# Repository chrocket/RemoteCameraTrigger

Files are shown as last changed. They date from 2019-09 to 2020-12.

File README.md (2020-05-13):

# RemoteCameraTrigger

SF30ReadEchoLCD2wWire  - Program  for - SF30 Lidar, LCD screen and trigger out to separate board with transmitter

CameraTriggerR2PCB  - PCB and software - Main camera trigger board using Adafruit LoRo module
CameraTriggerSensorNodeOnly - PCB and software - Sensor node only

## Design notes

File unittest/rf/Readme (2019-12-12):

RadioHead69_RawDemo_RX and RadioHead69_RawDemo_Tx are raw (broadcast send and receive)

 	Camera_remote_rx and  	Camera_remote_rx  are addressed (reliable versions)
  
  Used 	Camera_remote_rx for benchmarking, but used RadioHead69_RawDemo_RX RadioHead69_RawDemo_TX in the field

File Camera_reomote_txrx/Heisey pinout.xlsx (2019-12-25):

// inputs
LOWHIGH_TRIGGER_IN_PIN = 5; // If armed, Low to high transition will trigger
PUSH_IN_PIN=14; // Push button trigger overrided ("arm" does not have to be set)
ARM_IN_PIN=15; // Push button to arm sensor
POLLREQUEST_IN_PIN=16; // Push button to make roll call poll request
HIGHLOW_TRIGGER_IN_PIN=17; // If armed, High to low transition will trigger
DELAYMS_PIN=18; // Pot on analog in to set delay 0-200 ms
SPARE_PIN=19; // Reserved for future use
// outputs
// LED_OUT 13
BUZZER_OUT_PIN= 10; // Pin to audible indicator
CAMERA_TRIGGER_OUT_PIN = 11; // Pin for camera opto-isolator
CAMERA_FOCUS_OUT_PIN = 12; // Pin for focus opto-isoloatr
AUX_OUT_PIN = 9; // Pin for 2nd trigger output
ARM_INDICATOR_OUT_PIN = 6; // Indicates sensor is armed, turns laser on
ON_TIME_MS = 1000 ; // Camera bulb on time when trigger fires (typical vals 1-3 seconds)
SHORT_TIME_MS = 200;
 | RFM69_CS | 8
 | RFM69_INT | 3
 | RFM69_RESET | 4

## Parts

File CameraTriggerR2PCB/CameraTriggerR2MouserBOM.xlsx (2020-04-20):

Reference | Value | Footprint | Manf part no | Manf | Mouser PN | Datasheet
BZ1 | Buzzer | Buzzer_Beeper:Buzzer_TDK_PS1240P02BT_D12.2mm_H6.5mm | PS1240P02BT | TDK | 810-PS1240P02BT | ~
C1 | 25uf | Capacitor_THT:CP_Radial_Tantal_D5.0mm_P5.00mm | ESL107M016AC3AA | kmet | 80-ESL107M016AC3AA | ~
C2 | 0.1uf | Capacitor_THT:CP_Radial_Tantal_D5.0mm_P5.00mm | ESL106M100AE3AA | kimet | 80-ESL106M100AE3AA | ~
C3 | 0.01 uf | Capacitor_THT:C_Disc_D7.5mm_W2.5mm_P5.00mm | S103M47Z5UN63J7R | Vishay | 594-S103M47Z5UN63J7R
C4 | 0.01 uf | Capacitor_THT:C_Disc_D7.5mm_W2.5mm_P5.00mm | S103M47Z5UN63J7R | Vishay | 594-S103M47Z5UN63J7R
C5 | 0.01 uf | Capacitor_THT:C_Disc_D7.5mm_W2.5mm_P5.00mm | S103M47Z5UN63J7R | Vishay | 594-S103M47Z5UN63J7R
C6 | 0.01 uf | Capacitor_THT:C_Disc_D7.5mm_W2.5mm_P5.00mm | S103M47Z5UN63J7R | Vishay | 594-S103M47Z5UN63J7R
D1 | LED Arm |  | HLMP-1790 | Avago | 630-HLMP-1790 | ~
D2 | LED Trig |  | HLMP-K150 | Avago | 630-HLMP-K150 | ~
D3 | D |  | SBR10U45SD1-T | Diodes Incorporated | 621-SBR10U45SD1-T | DO-201AD-2
D4 | PWR |  | TLHK46Q1R2 | Vishay | 78-TLHK46Q1R2
D5 | Focus |  |  |  | HLMP-LG71-XZ0DD
IC1 | Feather M0 |  | 3178 | Adafruit | 485-3178
J1 | Power |  | XT30U-M | amass |  | https://www.tme.eu/Document/3cbfa5cfa544d79584972dd5234a409e/XT30U%20SPEC.pdf
J12 | 2.5 mm Camera Jack |  | SJ1-2503A | CUI | 490-SJ1-2503A
J11 | Ada2633 | 1x9 Header |  | Adafruit | 2633
J13 | 5V on | TerminalBlock_TE-Connectivity:TerminalBlock_TE_282834-2_1x02_P2.54mm_Horizontal | 282834-2 | TE | 571-282834-2
J14 | Pwr sw | TerminalBlock_TE-Connectivity:TerminalBlock_TE_282834-2_1x02_P2.54mm_Horizontal | 282834-2 | TE | 571-282834-2
J2 | Camera | Connector_Audio:Jack_3.5mm_CUI_SJ1-3533NG_Horizontal_CircularHoles | SJ1-3533NG | CUI | 490-SJ1-3533NG | ~https://www.mouser.com/datasheet/2/670/sj1-353xng-1313133.pdf
J3 | Aux out | TerminalBlock_TE-Connectivity:TerminalBlock_TE_282834-2_1x02_P2.54mm_Horizontal | 282834-2 | TE | 571-282834-2 | ~https://www.te.com/commerce/DocumentDelivery/DDEController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
J4 | Aux in | TerminalBlock_TE-Connectivity:TerminalBlock_TE_282834-3_1x03_P2.54mm_Horizontal | 282834-3 | TE | 571-2828343 | ~https://www.te.com/commerce/DocumentDelivery/DDEController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
J5 | Laser | TerminalBlock_TE-Connectivity:TerminalBlock_TE_282834-2_1x02_P2.54mm_Horizontal | 282834-2 | TE | 571-282834-2 | ~https://www.te.com/commerce/DocumentDelivery/DDEController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
J6 | Sensor | TerminalBlock_TE-Connectivity:TerminalBlock_TE_282834-3_1x03_P2.54mm_Horizontal | 282834-3 | TE | 571-2828343 | ~https://www.te.com/commerce/DocumentDelivery/DDEController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
J7 | Trig | TerminalBlock_TE-Connectivity:TerminalBlock_TE_282834-2_1x02_P2.54mm_Horizontal | 282834-2 | TE | 571-282834-2 | ~
J8 | Arm | TerminalBlock_TE-Connectivity:TerminalBlock_TE_282834-2_1x02_P2.54mm_Horizontal | 282834-2 | TE | 571-282834-2 | ~
Q1 | PN2222A | Package_TO_SOT_THT:TO-92_Inline | PN2222A | Central Semiconductor | 610-PN2222A | http://www.fairchildsemi.com/ds/PN/PN2222A.pdf
Q2 | PN2222A | Package_TO_SOT_THT:TO-92_Inline | PN2222A | Central Semiconductor | 610-PN2222A | http://www.fairchildsemi.com/ds/PN/PN2222A.pdf
Q3 | PN2222A | Package_TO_SOT_THT:TO-92_Inline | PN2222A | Central Semiconductor | 610-PN2222A | http://www.fairchildsemi.com/ds/PN/PN2222A.pdf
R1 | 1K | Resistor_THT:R_Axial_DIN0207_L6.3mm_D2.5mm_P7.62mm_Horizontal | MF1/4DCT26A1001F | KOA | 660-MF1/4DCT26A1001F | ~
R2 | 1k | Resistor_THT:R_Axial_DIN0207_L6.3mm_D2.5mm_P7.62mm_Horizontal | MF1/4DCT26A1001F | KOA | 660-MF1/4DCT26A1001F | ~
R3 | 5K | Resistor_THT:R_Axial_DIN0207_L6.3mm_D2.5mm_P7.62mm_Horizontal | MF1/4LCT52R472G | KOA | 660-MF1/4LCT52R472G | ~
R4 | 220
R5 | 1K | Resistor_THT:R_Axial_DIN0207_L6.3mm_D2.5mm_P7.62mm_Horizontal | MF1/4DCT26A1001F | KOA | 660-MF1/4DCT26A1001F | ~
R6 | 51 | Resistor_THT:R_Axial_DIN0207_L6.3mm_D2.5mm_P7.62mm_Horizontal | MF1/4LCT52R510G | KOA | 660-MF1/4LCT52R510G
R7 | 51 | Resistor_THT:R_Axial_DIN0207_L6.3mm_D2.5mm_P7.62mm_Horizontal | MF1/4LCT52R510G | KOA | 660-MF1/4LCT52R510G
R8 | 15K | Resistor_THT:R_Axial_DIN0207_L6.3mm_D2.5mm_P7.62mm_Horizontal |  |  | 603-MF0207FTE52-14K7
SW1 | SW_Power | Button_Switch_THT:SW_DIP_SPSTx01_Slide_9.78x4.72mm_W7.62mm_P2.54mm | AS11CB | NKK | 633-AS11CB | ~
SW2 | SW_Trigger | Button_Switch_THT:KSA_Tactile_SPST | KSA0A311LFTR | C&J | 611-KSA0A311LFT | ~http://www.ckswitches.com/media/1457/ksa_ksl.pdf
SW3 | SW_Poll | Button_Switch_THT:KSA_Tactile_SPST | KSA0A311LFTR | C&J | 611-KSA0A311LFT | ~http://www.ckswitches.com/media/1457/ksa_ksl.pdf
SW4 | SW_Arm | Button_Switch_THT:KSA_Tactile_SPST | KSA0A311LFTR | C&J | 611-KSA0A311LFT | ~http://www.ckswitches.com/media/1457/ksa_ksl.pdf
U1 | LM7805_TO220 | Package_TO_SOT_THT:TO-220-3_Vertical | LM7805CT | TI | 926-LM7805CT | http://www.fairchildsemi.com/ds/LM/LM7805.pdf
U2 | ILD74 | Package_DIP:DIP-6_W7.62mm | ILD74 | Vishay | 782-ILD74 | https://www.vishay.com/docs/83725/4n25.pdf
U3 | ILD74 | Package_DIP:DIP-6_W7.62mm | ILD74 | Vishay | 782-ILD74 | https://www.vishay.com/docs/83725/4n25.pdf
J11 |  | Connector_PinHeader_2.54mm:PinHeader_1x09_P2.54mm_Vertical | 2633 | Adafruit | 485-2633 | Adafruit Bluefruit LE SPI Friend - Bluetooth Low Energy (BLE)
 |  | Toggle switch | M2011SS1W01-BA | NKK | 633-M201101-BA
 |  | Project Box | 1591XXUSBK | Hammond | 546-1591XXUSBK
H1 |  | Standoffs | FC4542-632-A | Fascomp | 728-FC4542-632-A
H2 |  | Standoffs | FC4542-632-A | Fascomp | 728-FC4542-632-A
H3 |  | Standoffs | FC4542-632-A | Fascomp | 728-FC4542-632-A
H4 |  | Standoffs | FC4542-632-A | Fascomp | 728-FC4542-632-A

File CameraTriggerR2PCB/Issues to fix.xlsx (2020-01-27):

Rev 2 issues to fix
J1 symbols backwards on PCB | Fixed
2.5 mm has wrong footprint | TODO next rev; Use 3.5 mm
Headers 2830 should be regular not stacking 2886
R8 is wrong size
D5 missing HLMP-LG71-XZ0DD
J9, J10 too closely spaced
Need ground plane
Need wider trace for pwr
Watch square turns and T intersections
SW1 still has wrong spacing
Short 1 1K resister
Need AC decoupling caps
Add stensiling
Wrong footprint for J12

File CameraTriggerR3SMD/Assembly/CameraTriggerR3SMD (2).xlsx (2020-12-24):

Designator | Comment | Footprint | LCSC
BZ1 | Buzzer | Buzzer_Beeper:Buzzer_TDK_PS1240P02BT_D12.2mm_H6.5mm
C1 | 10u | Capacitor_SMD:C_1206_3216Metric | C13585
C2 | 4.7u | Capacitor_SMD:C_0603_1608Metric | C19666
C3 | 1u | Capacitor_SMD:C_0402_1005Metric | C52923
C4 | 4.7u | Capacitor_SMD:C_0603_1608Metric | C19666
C5 | 1u | Capacitor_SMD:C_0402_1005Metric | C52923
C6 | 0.01 Î¼F | Capacitor_SMD:C_0402_1005Metric | C1525
C7 | 0.01 Î¼F | Capacitor_SMD:C_0402_1005Metric | C1525
C8 | 0.01 Î¼F | Capacitor_SMD:C_0402_1005Metric | C1525
C9 | 0.01 Î¼F | Capacitor_SMD:C_0402_1005Metric | C1525
C10 | 10nf | Capacitor_SMD:C_0402_1005Metric | C15195
C11 | 10nf | Capacitor_SMD:C_0402_1005Metric | C15195
C12 | 10nf | Capacitor_SMD:C_0402_1005Metric | C15195
C13 | 10nf | Capacitor_SMD:C_0402_1005Metric | C15195
C14 | 4u7 | Capacitor_SMD:C_0603_1608Metric | C19666
C15 | 2u2 | Capacitor_SMD:C_0603_1608Metric | C23630
C16 | 100n | Capacitor_SMD:C_0402_1005Metric | C1525
C17 | 2u2 | Capacitor_SMD:C_0603_1608Metric | C23630
C18 | 100n | Capacitor_SMD:C_0402_1005Metric | C1525
C19 | 100n | Capacitor_SMD:C_0402_1005Metric | C1525
C20 | 100n | Capacitor_SMD:C_0402_1005Metric | C1525
C21 | 100n | Capacitor_SMD:C_0402_1005Metric | C1525
C22 | 1u | Capacitor_SMD:C_0402_1005Metric | C52923
C23 | 12p | Capacitor_SMD:C_0402_1005Metric | C1547
C24 | 10n | Capacitor_SMD:C_0402_1005Metric | C15195
C25 | 12p | Capacitor_SMD:C_0402_1005Metric | C1547
C26 | 100n | Capacitor_SMD:C_0402_1005Metric | C1525
C27 | 100n | Capacitor_SMD:C_0402_1005Metric | C1525
C28 | 10nf | Capacitor_SMD:C_0402_1005Metric | C15195
C29 | 100n | Capacitor_SMD:C_0402_1005Metric | C1525
C30 | 100n | Capacitor_SMD:C_0402_1005Metric | C1525
D1 | LED Trig (Red) | LED_SMD:LED_0603_1608Metric | C2286
D2 | LED Focus (Yellow) | LED_SMD:LED_0603_1608Metric | C72038
D3 | GREEN | LED_SMD:LED_0603_1608Metric | C72043
D4 | Red | LED_SMD:LED_0603_1608Metric | C2286
D5 | 1N4148W | Diode_SMD:D_SOD-323F | C2128
D6 | BLUE | LED_SMD:LED_0603_1608Metric | C72041
D7 | 19-237_R6GHBHC-A01_2T | 19237R6GHBHCA012T | C60105
F1 | 250mA | Fuse:Fuse_1206_3216Metric | C70068
FB1 | 600 @ 600 MHz | Inductor_SMD:L_0805_2012Metric | C1017
H1 | MountingHole_Pad | MountingHole:MountingHole_3.2mm_M3_Pad_Via
H2 | MountingHole_Pad | MountingHole:MountingHole_3.2mm_M3_Pad_Via
H3 | MountingHole_Pad | MountingHole:MountingHole_3.2mm_M3_Pad_Via
H4 | MountingHole_Pad | MountingHole:MountingHole_3.2mm_M3_Pad_Via
J1 | Camera 3.5mm | Connector_Audio:Jack_3.5mm_CUI_SJ1-3533NG_Horizontal_CircularHoles
J2 | Camera 2.5mm | CameraTriggerPCB:CUI_SJ1-2503A
J3 | Camera 3.5mm | Connector_Audio:Jack_3.5mm_CUI_SJ1-3533NG_Horizontal_CircularHoles
J4 | Camera 2.5mm | CameraTriggerPCB:CUI_SJ1-2503A
J5 | Sensor | TerminalBlock_TE-Connectivity:TerminalBlock_TE_282834-3_1x03_P2.54mm_Horizontal
J6 | Laser | TerminalBlock_TE-Connectivity:TerminalBlock_TE_282834-2_1x02_P2.54mm_Horizontal
J7 | XLR5 | SamacSys_Parts:Jack_XLR_Neutrik_NC5MBH_Horizontal
J8 | HighLowIn | TerminalBlock_TE-Connectivity:TerminalBlock_TE_282834-3_1x03_P2.54mm_Horizontal
J9 | Aux out | TerminalBlock_TE-Connectivity:TerminalBlock_TE_282834-2_1x02_P2.54mm_Horizontal
J10 | Trig | TerminalBlock_TE-Connectivity:TerminalBlock_TE_282834-2_1x02_P2.54mm_Horizontal
J11 | Arm | TerminalBlock_TE-Connectivity:TerminalBlock_TE_282834-2_1x02_P2.54mm_Horizontal
J12 | Conn_01x02 | Connector_AMASS:AMASS_XT30U-F_1x02_P5.0mm_Vertical
J13 | USB_B_Micro | Connector_USB:USB_Micro-B_Wuerth_629105150521
J14 | Qwiic_Connector | Connectors:1X04_1MM_RA_STRESSRELIEF
J15 | SWD | Connector_PinHeader_1.27mm:PinHeader_2x05_P1.27mm_Vertical_SMD
J16 | Conn_Coaxial | Connector_Coaxial:SMA_Amphenol_132289_EdgeMount
L1 | 39n | Inductor_SMD:L_0402_1005Metric | C26443
Q1 | S9103 | Package_TO_SOT_SMD:SOT-23 | C6749
Q2 | S9103 | Package_TO_SOT_SMD:SOT-23 | C6749
Q3 | AO3401A | Package_TO_SOT_SMD:SOT-23 | C15127
Q4 | S9103 | Package_TO_SOT_SMD:SOT-23 | C6749
Q5 | S9103 | Package_TO_SOT_SMD:SOT-23 | C6749
R1 | 47 | Resistor_SMD:R_0402_1005Metric | C25118
R2 | 1.5K | Resistor_SMD:R_0603_1608Metric | C22843
R3 | 47 | Resistor_SMD:R_0402_1005Metric | C25118
R4 | 1.5K | Resistor_SMD:R_0603_1608Metric | C22843
R5 | 20K | Resistor_SMD:R_0603_1608Metric | C4184
R6 | 10K | Resistor_SMD:R_0402_1005Metric | C25744
R7 | 1k5 | Resistor_SMD:R_0603_1608Metric | C22843
R8 | 1K | Resistor_SMD:R_0603_1608Metric | C21190
R9 | 15K | Resistor_SMD:R_0603_1608Metric | C22809
R10 | 1k5 | Resistor_SMD:R_0603_1608Metric | C22843
R11 | 5K | Resistor_SMD:R_0402_1005Metric | C25744
R12 | 1.5K | Resistor_SMD:R_0603_1608Metric | C22843
R13 | 47 | Resistor_SMD:R_0402_1005Metric | C25118
R14 | 10k | Resistor_SMD:R_0402_1005Metric | C25744
R15 | 2k2 | Resistor_SMD:R_0402_1005Metric | C25879
R16 | 2k2 | Resistor_SMD:R_0402_1005Metric | C25879
R17 | 22 | Resistor_SMD:R_0402_1005Metric | C25092
R18 | 22 | Resistor_SMD:R_0402_1005Metric | C25092
R19 | 22 | Resistor_SMD:R_0402_1005Metric | C25092
R20 | 22 | Resistor_SMD:R_0402_1005Metric | C25092
R21 | 1k5 | Resistor_SMD:R_0603_1608Metric | C22843
R22 | 1K | Resistor_SMD:R_0402_1005Metric | C11702
R23 | 1K | Resistor_SMD:R_0402_1005Metric | C11702
R24 | 1K | Resistor_SMD:R_0402_1005Metric | C11702
R25 | 100 | Resistor_SMD:R_0603_1608Metric | C22775
SW1 | SW_SPST | Button_Switch_THT:SW_DIP_SPSTx01_Slide_9.78x4.72mm_W7.62mm_P2.54mm
SW2 | SW_SPDT | Button_Switch_THT:SW_Slide_1P2T_CK_OS102011MS2Q
SW3 | SW_Trigger | Button_Switch_THT:KSA_Tactile_SPST | C127509
SW4 | SW_Arm | Button_Switch_THT:KSA_Tactile_SPST | C127509
SW5 | SW_Poll | Button_Switch_THT:KSA_Tactile_SPST | C127509
SW6 | SW_SPDT | Button_Switch_SMD:SW_SPDT_PCM12
SW7 | SW_Push | Button_Switch_SMD:SW_SPST_CK_KXT3
U1 | TLP291-4 | Package_SO:SOIC-16_4.55x10.3mm_P1.27mm | C60900
U2 | L7805 | Package_TO_SOT_SMD:TO-252-2 | C310413
U3 | UZ1084 | Package_TO_SOT_SMD:TO-252-2 | C84897
U4 | STM32F405RGTx | Package_QFP:LQFP-64_10x10mm_P0.5mm | C15742
U5 | RN4871 | RF_Module:Microchip_RN4871
U6 | RFM95W-915S2 | RF_Module:HOPERF_RFM9XW_THT
Y1 | Crystal_GND24_Small | Crystal:Crystal_SMD_3225-4Pin_3.2x2.5mm | C13738

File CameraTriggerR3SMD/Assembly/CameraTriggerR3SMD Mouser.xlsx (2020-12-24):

Designator | Comment | Footprint | Mouser | Digikey
BZ1 | Buzzer | Buzzer_Beeper:Buzzer_TDK_PS1240P02BT_D12.2mm_H6.5mm | 810-PS1240P02BT
J1 | Camera 3.5mm | Connector_Audio:Jack_3.5mm_CUI_SJ1-3533NG_Horizontal_CircularHoles | 490-SJ1-3533NG
J2 | Camera 2.5mm | CameraTriggerPCB:CUI_SJ1-2503A | 490-SJ1-2503A
J3 | Camera 3.5mm | Connector_Audio:Jack_3.5mm_CUI_SJ1-3533NG_Horizontal_CircularHoles | 490-SJ1-3533NG
J4 | Camera 2.5mm | CameraTriggerPCB:CUI_SJ1-2503A | 490-SJ1-2503A
J5 | Sensor | TerminalBlock_TE-Connectivity:TerminalBlock_TE_282834-3_1x03_P2.54mm_Horizontal | 571-2828343
J6 | Laser | TerminalBlock_TE-Connectivity:TerminalBlock_TE_282834-2_1x02_P2.54mm_Horizontal | 571-282834-2
J7 | XLR5 | SamacSys_Parts:Jack_XLR_Neutrik_NC5MBH_Horizontal | 568-NC5MBH
J8 | HighLowIn | TerminalBlock_TE-Connectivity:TerminalBlock_TE_282834-3_1x03_P2.54mm_Horizontal | 571-2828343
J9 | Aux out | TerminalBlock_TE-Connectivity:TerminalBlock_TE_282834-2_1x02_P2.54mm_Horizontal | 571-282834-2
J10 | Trig | TerminalBlock_TE-Connectivity:TerminalBlock_TE_282834-2_1x02_P2.54mm_Horizontal | 571-282834-2
J11 | Arm | TerminalBlock_TE-Connectivity:TerminalBlock_TE_282834-2_1x02_P2.54mm_Horizontal | 571-282834-2
J13 | USB_B_Micro | Connector_USB:USB_Micro-B_Wuerth_629105150521 | 629105150521
J14 | Qwiic_Connector | Connectors:1X04_1MM_RA_STRESSRELIEF | 474-PRT-14417
J15 | SWD | Connector_PinHeader_1.27mm:PinHeader_2x05_P1.27mm_Vertical_SMD | FTR-105-01-L-D-A
J16 | Conn_Coaxial | Connector_Coaxial:SMA_Amphenol_132289_EdgeMount | 523-132289
SW1 | SW_SPST | Button_Switch_THT:SW_DIP_SPSTx01_Slide_9.78x4.72mm_W7.62mm_P2.54mm | 633-AS11CB
SW2 | SW_SPDT | Button_Switch_THT:SW_Slide_1P2T_CK_OS102011MS2Q | 611-OS102011MS2QN1
SW6 | SW_SPDT | Button_Switch_SMD:SW_SPDT_PCM12 | PCM12SMTR
SW7 | SW_Push | Button_Switch_SMD:SW_SPST_CK_KXT3 | 611-KXT321LHS
U5 | RN4871 | RF_Module:Microchip_RN4871 |  | RN4871-V/RM118-ND
U6 | RFM95W-915S2 | RF_Module:HOPERF_RFM9XW_THT | 223-RFM95W-915S2 | RFM95W-915S2-ND | 1597-1491-ND
 |  | Programmer ST-LINK/V2 | 511-ST-LINK/V2 | 497-10484-ND
 |  | Adapter ARM-JTAG-20-10 | 909-ARM-JTAG-20-10 | 1188-1016-ND

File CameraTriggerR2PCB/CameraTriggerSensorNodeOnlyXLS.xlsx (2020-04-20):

Item | Qty | Reference(s) | Value | Manf part no | Manf | Mouser PN
1 | 1 | BZ1 | Buzzer | PS1240P02BT | TDK | 810-PS1240P02BT
2 | 1 | C1 | 25uf | ESL107M016AC3AA | kmet | 80-ESL107M016AC3AA
3 | 1 | C2 | 0.1uf | ESL106M100AE3AA | kimet | 80-ESL106M100AE3AA
4 | 4 | C3, C4, C5, C6 | 0.01uF | S103M47Z5UN63J7R | Vishay | 594-S103M47Z5UN63J7R | 72-VY2103M63Y5US63V0
5 | 1 | D1 | LED Arm | HLMP-1790 | Avago | 630-HLMP-1790
6 | 1 | D2 | LED Trig | HLMP-K150 | Avago | 630-HLMP-K150
7 | 1 | D3 | D | SBR10U45SD1-T | Diodes Incorporated | 621-SBR10U45SD1-T
8 | 1 | D4 | PWR | TLHK46Q1R2 | Vishay | 78-TLHK46Q1R2
12 | 1 | IC1 | 3178 | 3178 | Adafruit | 485-3178
13 | 1 | J1 | Power | 282834-2 | TE | 571-282834-2
14 | 1 | J2 | Qwiic_Connector | PRT-14417 | Sparkfun | 474-PRT-14417
15 | 1 | J3 | Aux out | 282834-2 | TE | 571-282834-2
16 | 1 | J4 | HighLowIn | 282834-3 | TE | 571-2828343
17 | 1 | J5 | Laser | 282834-2 | TE | 571-282834-2
18 | 1 | J6 | Sensor | 282834-3 | TE | 571-2828343
19 | 1 | J13 | Serial | 282834-4 | TE | 571-282834-4
20 | 1 | J14 | Ext power switch | 282834-2 | TE | 571-282834-2
21 | 1 | Q1 | PN2222A | PN2222A | Central Semiconductor | 610-PN2222A
22 | 2 | R1, R5 | 1K | MF1/4DCT26A1001F | KOA | 660-MF1/4DCT26A1001F | 603-MF0204FTE52-1K | 660-MF1/4DCT26A1001F
23 | 1 | R3 | 5K | MF1/4LCT52R472G | KOA | 660-MF1/4LCT52R472G
24 | 1 | R4 | 220 |  |  | 603-MF0207FTE52-14K7
25 | 1 | R8 | 15K |  |  | 603-MF0207FTE52-14K7
26 | 1 | RV1 | 1K | RK09K1130AV7 | Alps | 688-RK09K1130AV7
27 | 1 | SW1 | AS11CB | AS11CB | NKK | 633-AS11CB
28 | 1 | SW3 | SW_Poll | KSA0A311LFTR | C&J | 611-KSA0A311LFT
29 | 1 | U1 | LM7805_TO220 | LM7805CT | TI | 926-LM7805CT
 | 1 |  | Connector_PinHeader_2.54mm:PinHeader_1x09_P2.54mm_Vertical | 2886 | Adafruit | 485-2886
 | 1 |  | Toggle switch | M2011SS1W01-BA | NKK | 633-M201101-BA
 | 1 |  | Project Box | 1591XXUSBK | Hammond | 546-1591XXUSBK
 | 4 |  | Standoffs | FC4542-632-A | Fascomp | 728-FC4542-632-A

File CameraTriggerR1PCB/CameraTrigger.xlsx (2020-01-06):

Reference | Value | Footprint |  |  | Mouser PN | Datasheet
BZ1 | Buzzer | Buzzer_Beeper:Buzzer_TDK_PS1240P02BT_D12.2mm_H6.5mm | PS1240P02BT | TDK | 810-PS1240P02BT | ~
C1 | 25uf | Capacitor_THT:CP_Radial_Tantal_D5.0mm_P5.00mm | ESL107M016AC3AA | kmet | 80-ESL107M016AC3AA | ~
C2 | 0.1uf | Capacitor_THT:CP_Radial_Tantal_D5.0mm_P5.00mm | ESL106M100AE3AA | kimet | 80-ESL106M100AE3AA | ~
D1 | LED Arm | LED_THT:LED_D2.0mm_W4.8mm_H2.5mm_FlatTop | HLMP-1790 | Avago | 630-HLMP-1790 | ~
D2 | LED Trig | LED_THT:LED_D2.0mm_W4.8mm_H2.5mm_FlatTop | HLMP-NG07 | Avago | 630-HLMP-NG07 | ~
D3 |  |  | SBR10U45SD1-T | Diodes Incorporated | 621-SBR10U45SD1-T | DO-201AD-2
J1 | Power | TerminalBlock_TE-Connectivity:TerminalBlock_TE_282834-2_1x02_P2.54mm_Horizontal | 282834-2 | TE | 571-282834-2 | ~https://www.te.com/commerce/DocumentDelivery/DDEController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
J10 | feather short | Connector_PinHeader_2.54mm:PinHeader_1x12_P2.54mm_Vertical | 2830 | Adafruit | 485-2830 | ~
J4 | Aux in | TerminalBlock_TE-Connectivity:TerminalBlock_TE_282834-3_1x03_P2.54mm_Horizontal | 282834-3 | TE | 571-2828343 | ~https://www.te.com/commerce/DocumentDelivery/DDEController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
J2 | Camera | Connector_Audio:Jack_3.5mm_CUI_SJ1-3533NG_Horizontal_CircularHoles | SJ1-3533NG | CUI | 490-SJ1-3533NG | ~https://www.mouser.com/datasheet/2/670/sj1-353xng-1313133.pdf
J3 | Aux out | TerminalBlock_TE-Connectivity:TerminalBlock_TE_282834-2_1x02_P2.54mm_Horizontal | 282834-2 | TE | 571-282834-2 | ~https://www.te.com/commerce/DocumentDelivery/DDEController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
J5 | Laser | TerminalBlock_TE-Connectivity:TerminalBlock_TE_282834-2_1x02_P2.54mm_Horizontal | 282834-2 | TE | 571-282834-2 | ~https://www.te.com/commerce/DocumentDelivery/DDEController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
J6 | Sensor | TerminalBlock_TE-Connectivity:TerminalBlock_TE_282834-3_1x03_P2.54mm_Horizontal | 282834-3 | TE | 571-2828343 | ~https://www.te.com/commerce/DocumentDelivery/DDEController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
J7 | Trig | TerminalBlock_TE-Connectivity:TerminalBlock_TE_282834-2_1x02_P2.54mm_Horizontal | 282834-2 | TE | 571-282834-2 | ~
J8 | Arm | TerminalBlock_TE-Connectivity:TerminalBlock_TE_282834-2_1x02_P2.54mm_Horizontal | 282834-2 | TE | 571-282834-2 | ~
Q1 | PN2222A | Package_TO_SOT_THT:TO-92_Inline | PN2222A | Central Semiconductor | 610-PN2222A | http://www.fairchildsemi.com/ds/PN/PN2222A.pdf
Q2 | PN2222A | Package_TO_SOT_THT:TO-92_Inline | PN2222A | Central Semiconductor | 610-PN2222A | http://www.fairchildsemi.com/ds/PN/PN2222A.pdf
Q3 | PN2222A | Package_TO_SOT_THT:TO-92_Inline | PN2222A | Central Semiconductor | 610-PN2222A | http://www.fairchildsemi.com/ds/PN/PN2222A.pdf
R1 | 1K | Resistor_THT:R_Axial_DIN0207_L6.3mm_D2.5mm_P7.62mm_Horizontal | MF1/4DCT26A1001F | KOA | 660-MF1/4DCT26A1001F | ~
R2 | 1k | Resistor_THT:R_Axial_DIN0207_L6.3mm_D2.5mm_P7.62mm_Horizontal | MF1/4DCT26A1001F | KOA | 660-MF1/4DCT26A1001F | ~
R3 | 5K | Resistor_THT:R_Axial_DIN0207_L6.3mm_D2.5mm_P7.62mm_Horizontal | MF1/4LCT52R472G | KOA | 660-MF1/4LCT52R472G | ~
R5 | 1K | Resistor_THT:R_Axial_DIN0207_L6.3mm_D2.5mm_P7.62mm_Horizontal | MF1/4DCT26A1001F | KOA | 660-MF1/4DCT26A1001F | ~
SW1 | SW_Power | Button_Switch_THT:SW_DIP_SPSTx01_Slide_9.78x4.72mm_W7.62mm_P2.54mm | AS11BH | NKK | 633-AS11BH | ~
SW2 | SW_Trigger | Button_Switch_THT:KSA_Tactile_SPST | KSA0A311LFTR | C&J | 611-KSA0A311LFT | ~http://www.ckswitches.com/media/1457/ksa_ksl.pdf
SW3 | SW_Poll | Button_Switch_THT:KSA_Tactile_SPST | KSA0A311LFTR | C&J | 611-KSA0A311LFT | ~http://www.ckswitches.com/media/1457/ksa_ksl.pdf
SW4 | SW_Arm | Button_Switch_THT:KSA_Tactile_SPST | KSA0A311LFTR | C&J | 611-KSA0A311LFT | ~http://www.ckswitches.com/media/1457/ksa_ksl.pdf
U1 | LM7805_TO220 | Package_TO_SOT_THT:TO-220-3_Vertical | LM7805CT | TI | 926-LM7805CT | http://www.fairchildsemi.com/ds/LM/LM7805.pdf
U2 | ILD74 | Package_DIP:DIP-6_W7.62mm | ILD74 | Vishay | 782-ILD74 | https://www.vishay.com/docs/83725/4n25.pdf
U3 | ILD74 | Package_DIP:DIP-6_W7.62mm | ILD74 | Vishay | 782-ILD74 | https://www.vishay.com/docs/83725/4n25.pdf
U6 | Feather M0 |  | 3176 | Adafruit | 485-3176
J12 | 2.5 mm Camera Jack |  | SJ1-2503A | CUI | 490-SJ1-2503A
U7 |  | Connector_PinHeader_2.54mm:PinHeader_1x09_P2.54mm_Vertical | 2633 | Adafruit |  | Adafruit Bluefruit LE SPI Friend - Bluetooth Low Energy (BLE)

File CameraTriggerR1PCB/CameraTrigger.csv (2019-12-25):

Reference | Value | Footprint | Datasheet
J3 | Aux out | TerminalBlock_TE-Connectivity:TerminalBlock_TE_282834-2_1x02_P2.54mm_Horizontal | ~https://www.te.com/commerce/DocumentDelivery/DDEController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
J4 | Aux in | TerminalBlock_TE-Connectivity:TerminalBlock_TE_282834-2_1x02_P2.54mm_Horizontal | ~https://www.te.com/commerce/DocumentDelivery/DDEController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
J5 | Laser | TerminalBlock_TE-Connectivity:TerminalBlock_TE_282834-2_1x02_P2.54mm_Horizontal | ~https://www.te.com/commerce/DocumentDelivery/DDEController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
J6 | Sensor | TerminalBlock_TE-Connectivity:TerminalBlock_TE_282834-3_1x03_P2.54mm_Horizontal | ~https://www.te.com/commerce/DocumentDelivery/DDEController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
SW2 | SW_Trigger | Button_Switch_THT:KSA_Tactile_SPST | ~http://www.ckswitches.com/media/1457/ksa_ksl.pdf
SW4 | SW_Arm | Button_Switch_THT:KSA_Tactile_SPST | ~http://www.ckswitches.com/media/1457/ksa_ksl.pdf
SW3 | SW_Poll | Button_Switch_THT:KSA_Tactile_SPST | ~http://www.ckswitches.com/media/1457/ksa_ksl.pdf
U2 | 4N25 | Package_DIP:DIP-6_W7.62mm | https://www.vishay.com/docs/83725/4n25.pdf
D1 | LED Arm | LED_THT:LED_D2.0mm_W4.8mm_H2.5mm_FlatTop | ~
R1 | 1K | Resistor_THT:R_Axial_DIN0207_L6.3mm_D2.5mm_P7.62mm_Horizontal | ~
J2 | Camera | Connector_Audio:Jack_3.5mm_CUI_SJ1-3533NG_Horizontal_CircularHoles | ~https://www.mouser.com/datasheet/2/670/sj1-353xng-1313133.pdf
R2 | 220 | Resistor_THT:R_Axial_DIN0207_L6.3mm_D2.5mm_P7.62mm_Horizontal | ~
BZ1 | Buzzer | Buzzer_Beeper:Buzzer_TDK_PS1240P02BT_D12.2mm_H6.5mm | ~
J7 | Trig | TerminalBlock_TE-Connectivity:TerminalBlock_TE_282834-2_1x02_P2.54mm_Horizontal | ~
J8 | Arm | TerminalBlock_TE-Connectivity:TerminalBlock_TE_282834-2_1x02_P2.54mm_Horizontal | ~
D2 | LED Trig | LED_THT:LED_D2.0mm_W4.8mm_H2.5mm_FlatTop | ~
R3 | 5K | Resistor_THT:R_Axial_DIN0207_L6.3mm_D2.5mm_P7.62mm_Horizontal | ~
Q1 | PN2222A | Package_TO_SOT_THT:TO-92_Inline | http://www.fairchildsemi.com/ds/PN/PN2222A.pdf
J9 | feather long | Connector_PinHeader_2.54mm:PinHeader_1x16_P2.54mm_Vertical | ~
J10 | feather short | Connector_PinHeader_2.54mm:PinHeader_1x12_P2.54mm_Vertical | ~
J11 | Spare | TerminalBlock_TE-Connectivity:TerminalBlock_TE_282834-2_1x02_P2.54mm_Horizontal | ~https://www.te.com/commerce/DocumentDelivery/DDEController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
R4 | 5K | Resistor_THT:R_Axial_DIN0207_L6.3mm_D2.5mm_P7.62mm_Horizontal | ~
U3 | 4N25 | Package_DIP:DIP-6_W7.62mm | https://www.vishay.com/docs/83725/4n25.pdf
R5 | 220 | Resistor_THT:R_Axial_DIN0207_L6.3mm_D2.5mm_P7.62mm_Horizontal | ~
RV1 | 10K | Potentiometer_THT:Potentiometer_Alps_RK09K_Single_Vertical | ~
C2 | 0.1uf | Capacitor_THT:CP_Radial_Tantal_D5.0mm_P5.00mm | ~
C1 | 25uf | Capacitor_THT:CP_Radial_Tantal_D5.0mm_P5.00mm | ~
J1 | Power | TerminalBlock_TE-Connectivity:TerminalBlock_TE_282834-2_1x02_P2.54mm_Horizontal | ~https://www.te.com/commerce/DocumentDelivery/DDEController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
SW1 | SW_Power | Button_Switch_THT:SW_DIP_SPSTx01_Slide_9.78x4.72mm_W7.62mm_P2.54mm | ~
U1 | LM7805_TO220 | Package_TO_SOT_THT:TO-220-3_Vertical | http://www.fairchildsemi.com/ds/LM/LM7805.pdf

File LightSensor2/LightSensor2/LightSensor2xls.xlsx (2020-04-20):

 | Designator | Package |  | Quantity | Mouser
1 | U1 | DIP-8_W7.62mm_LongPads | 1 | LTC1050CN8PBF | 584-LTC1050CN8#PBF
2 | J1 | TerminalBlock_TE_282834-3_1x03_P2.54mm_Horizontal | 1 | J1 | 571-2828343
3 | D1 | LED_D5.0mm_IRGrey | 1 | SFH229 | 720-SFH229FA
4 | 10K1 | R_Axial_DIN0207_L6.3mm_D2.5mm_P10.16mm_Horizontal | 1 | R | MF0207FTE52-10K
 |  |  |  |  | 720-SFH229

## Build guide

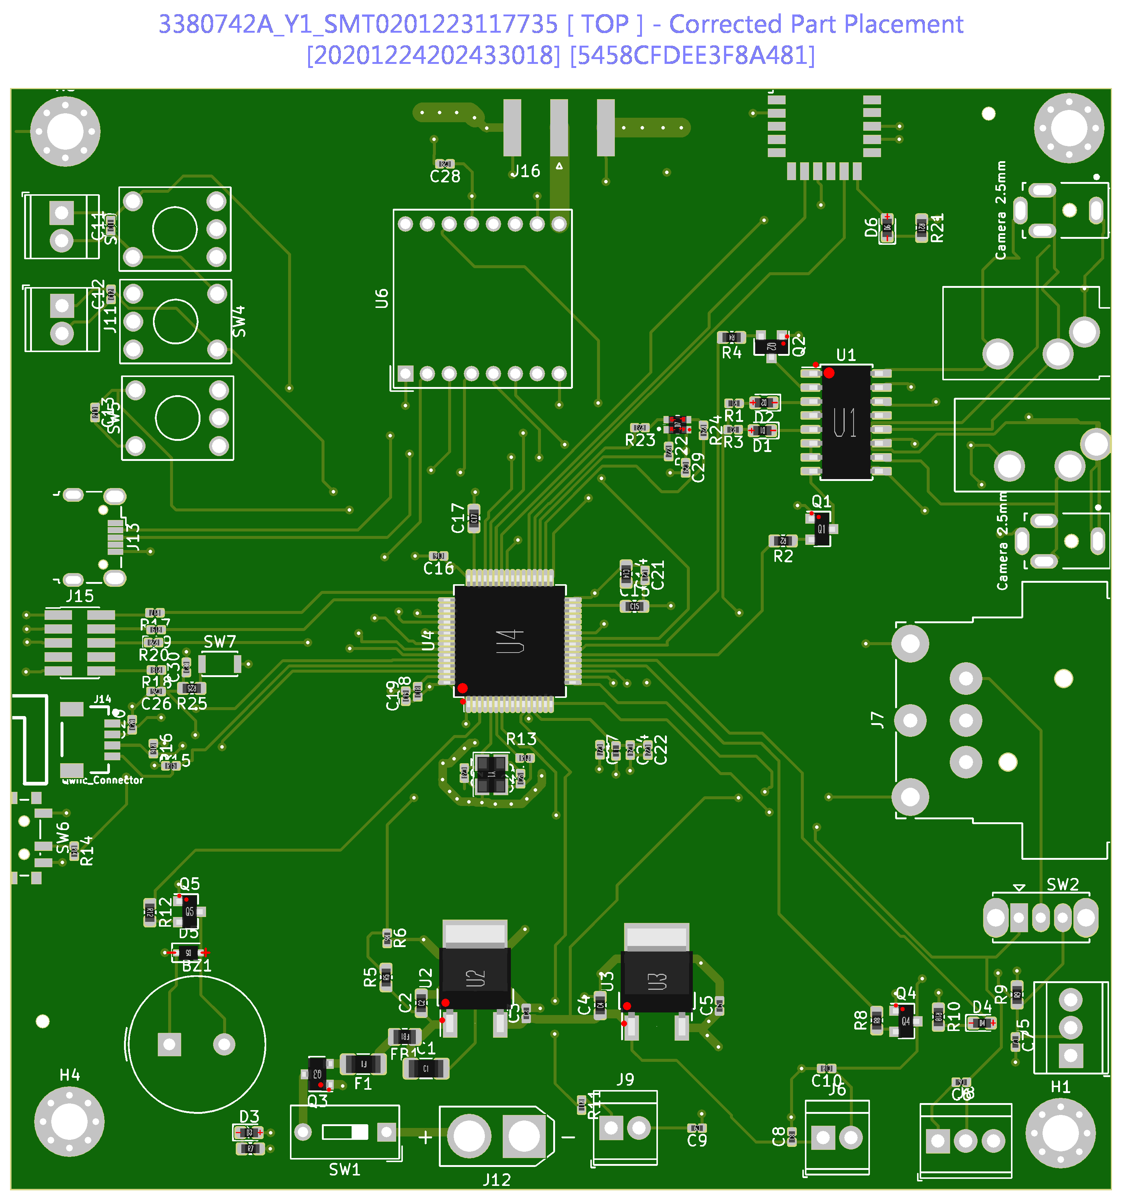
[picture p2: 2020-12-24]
CameraTriggerR3SMD/Assembly/Produce_DanZhi.SMT_Snapshot.Top.3380742A_Y1.SMT0201223117735(1).png

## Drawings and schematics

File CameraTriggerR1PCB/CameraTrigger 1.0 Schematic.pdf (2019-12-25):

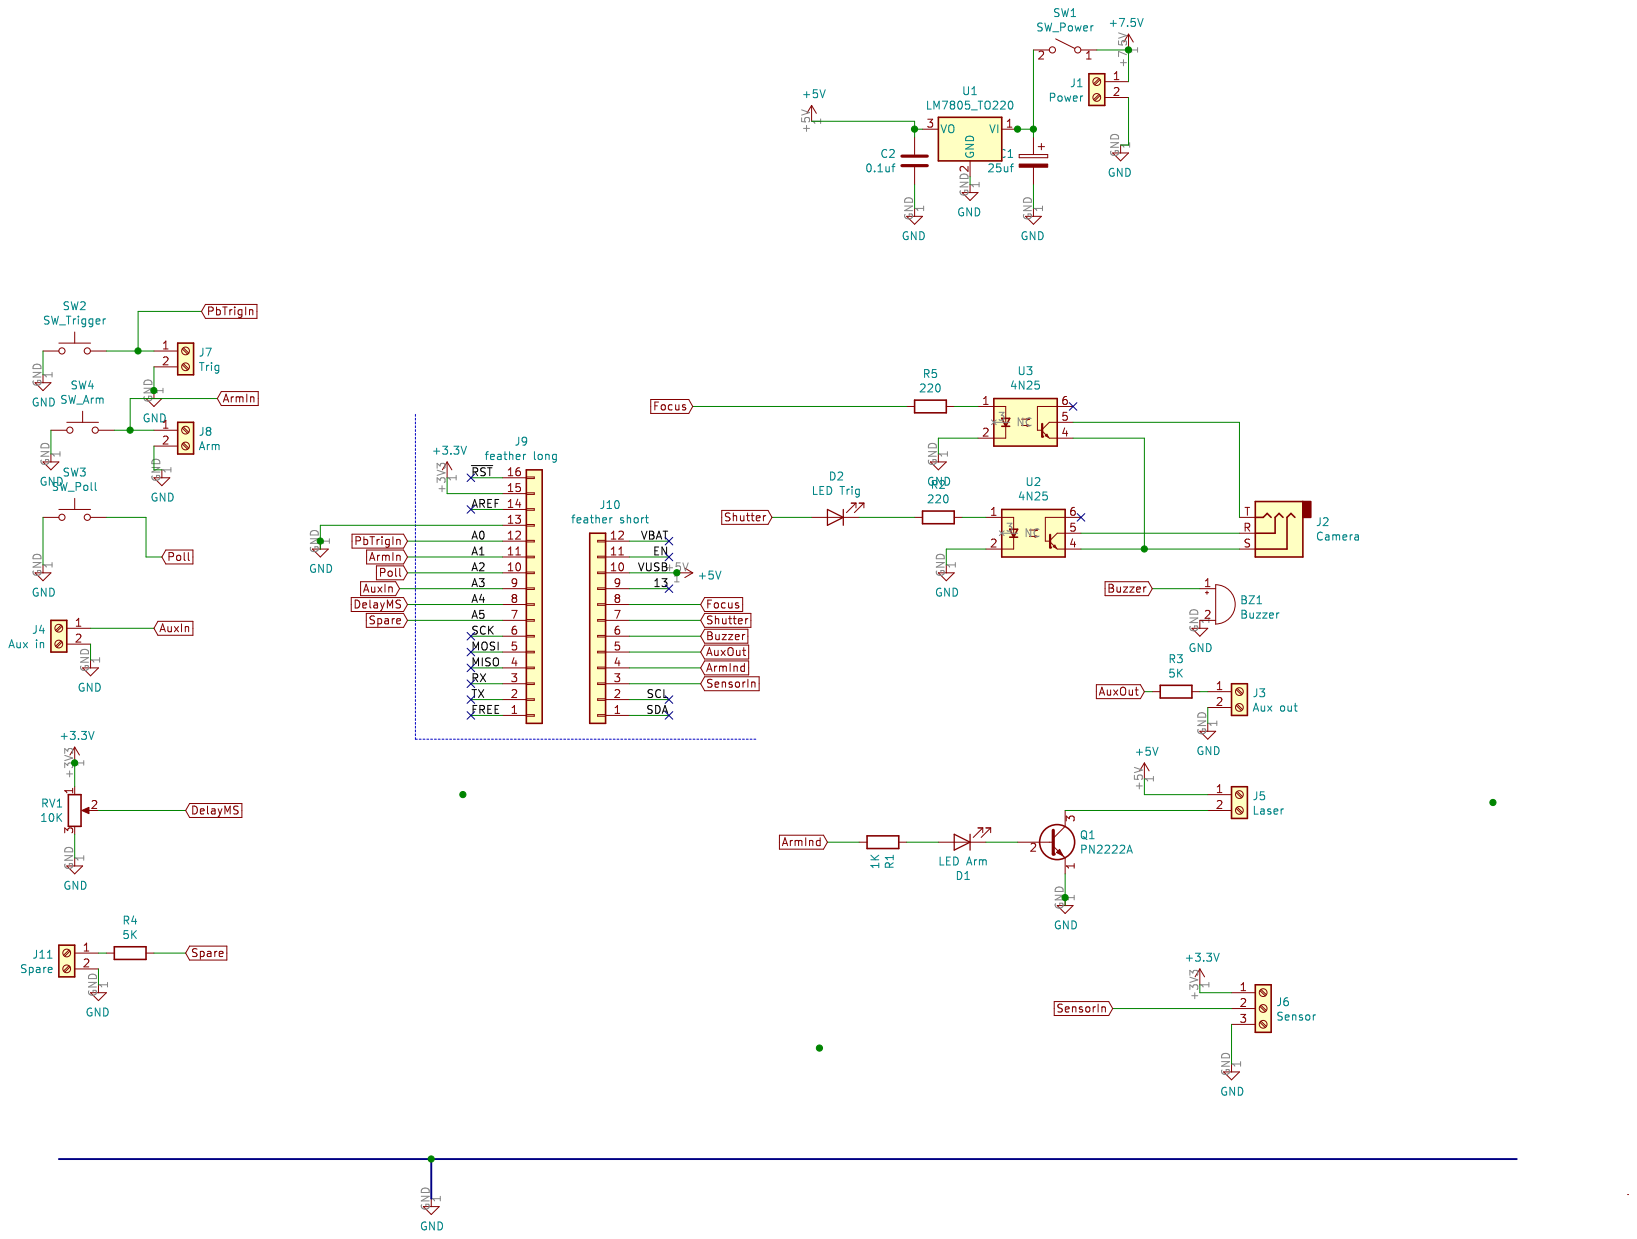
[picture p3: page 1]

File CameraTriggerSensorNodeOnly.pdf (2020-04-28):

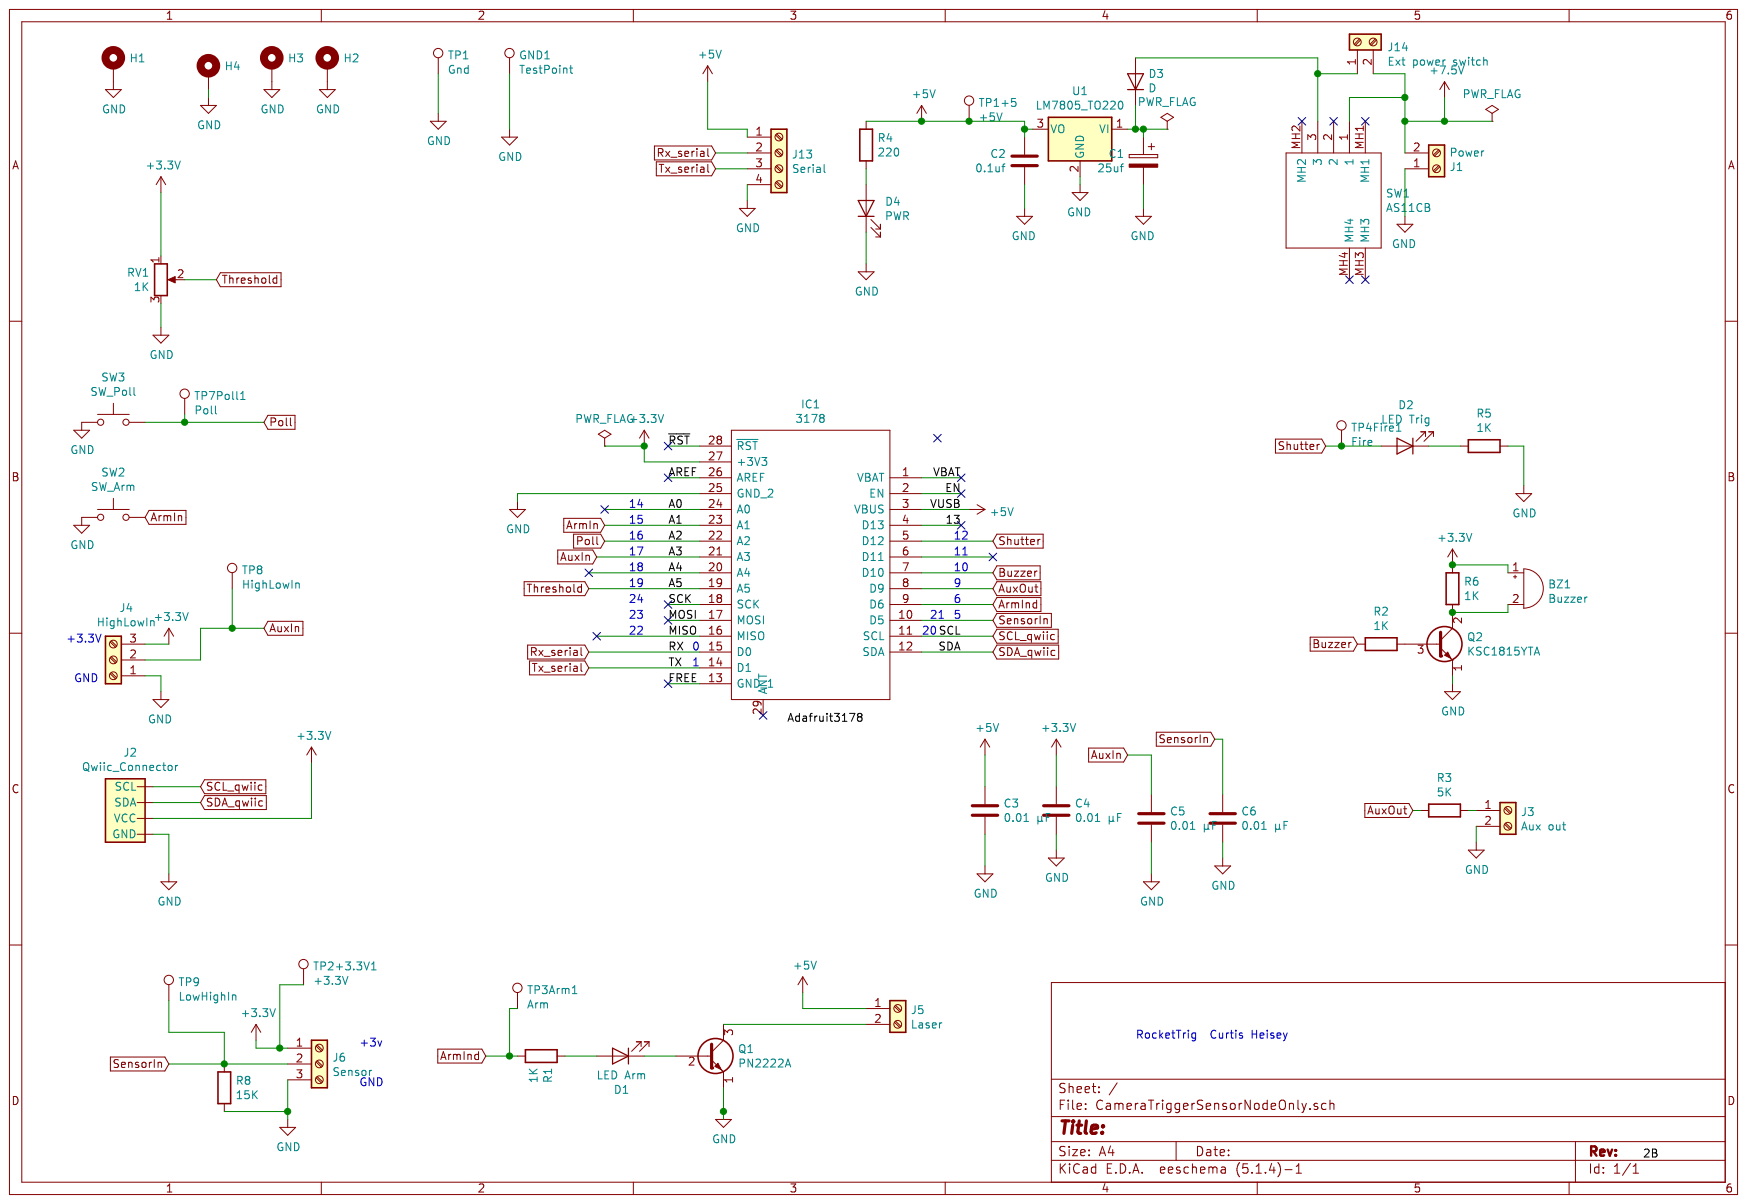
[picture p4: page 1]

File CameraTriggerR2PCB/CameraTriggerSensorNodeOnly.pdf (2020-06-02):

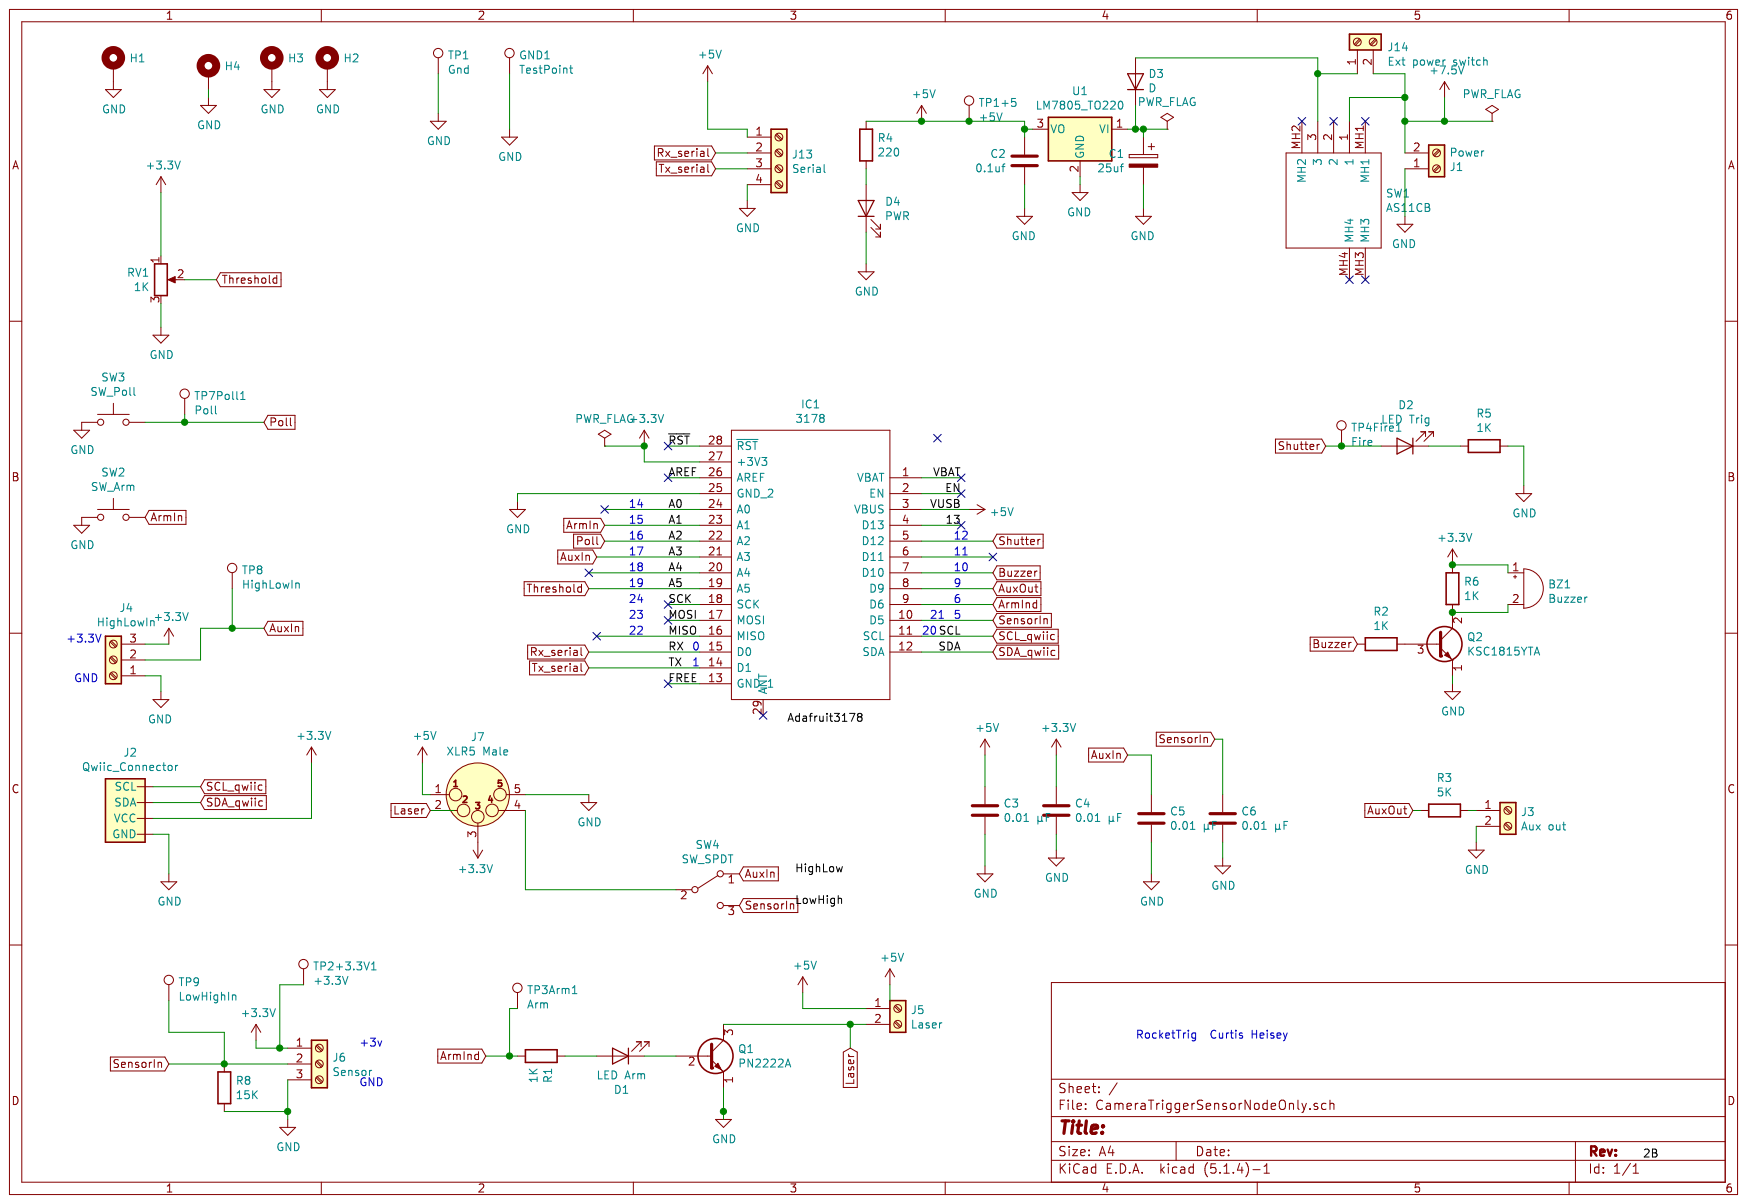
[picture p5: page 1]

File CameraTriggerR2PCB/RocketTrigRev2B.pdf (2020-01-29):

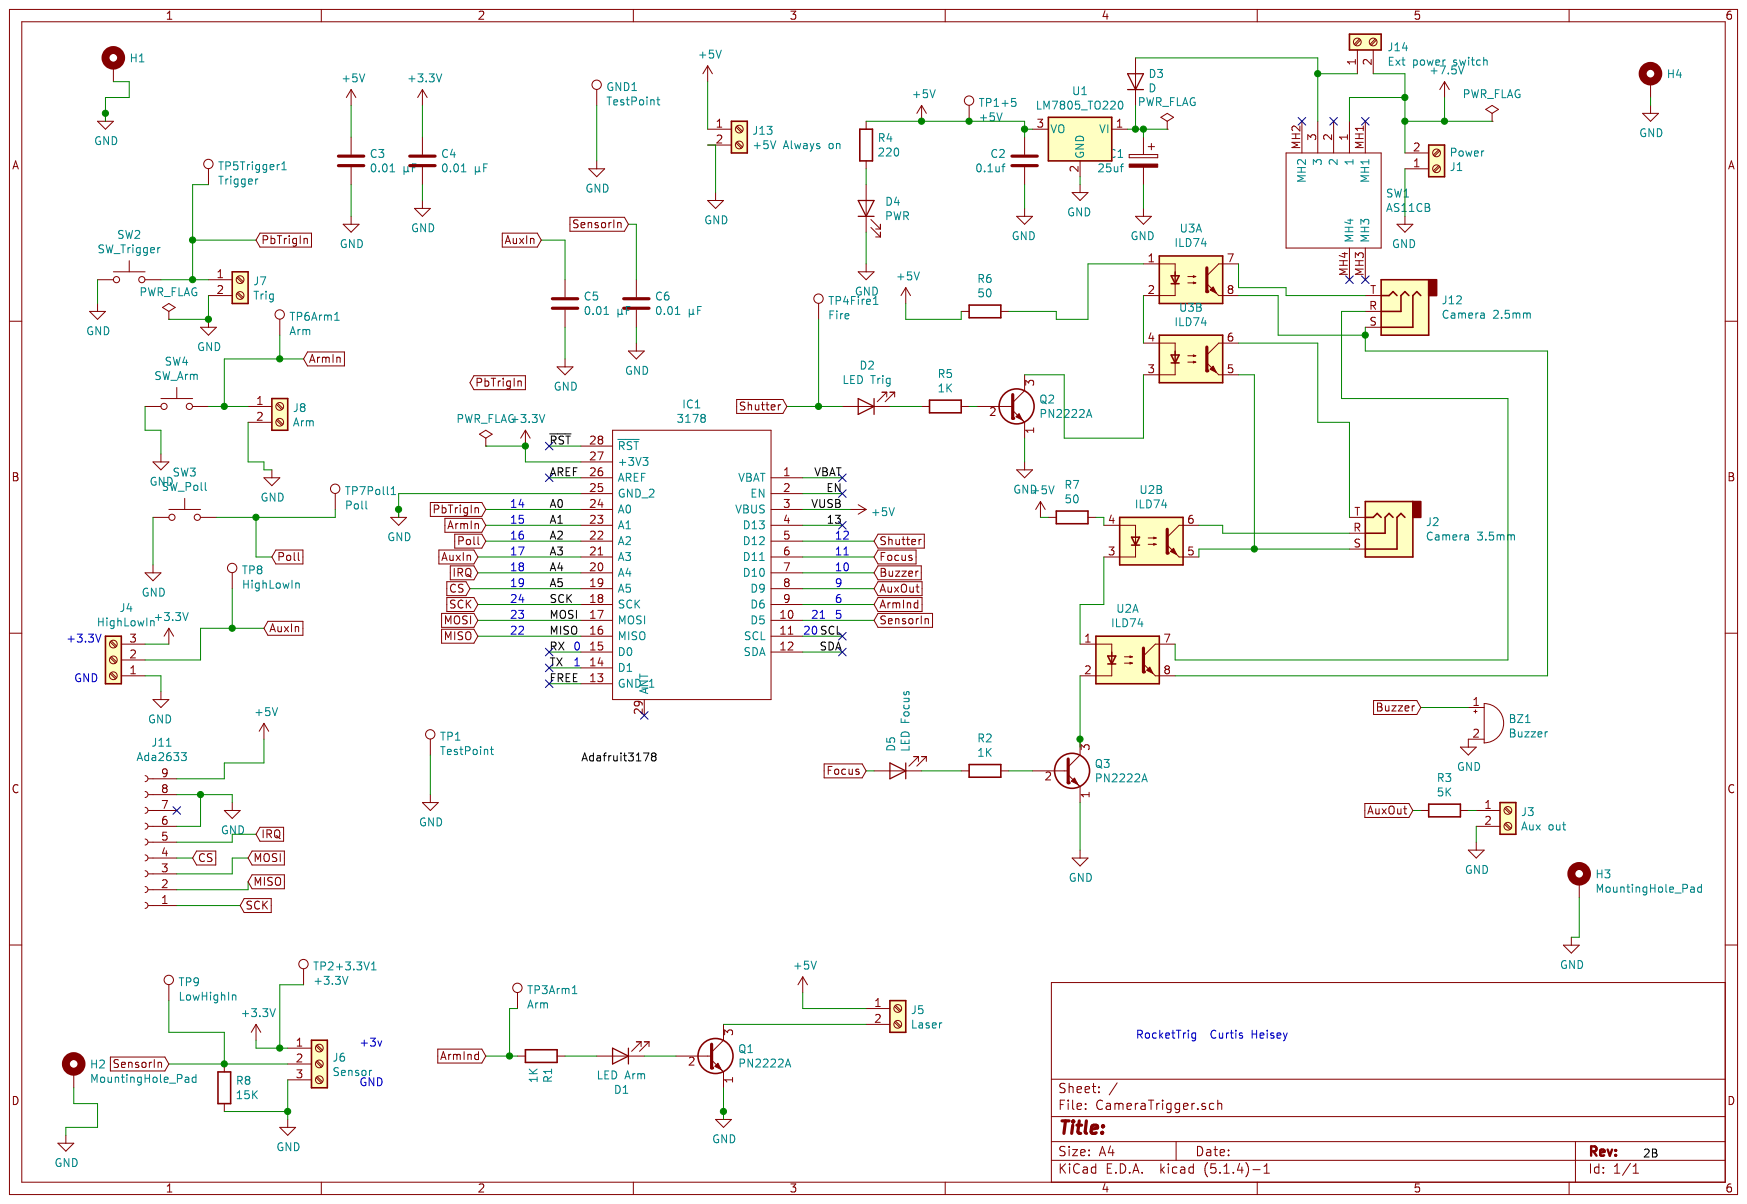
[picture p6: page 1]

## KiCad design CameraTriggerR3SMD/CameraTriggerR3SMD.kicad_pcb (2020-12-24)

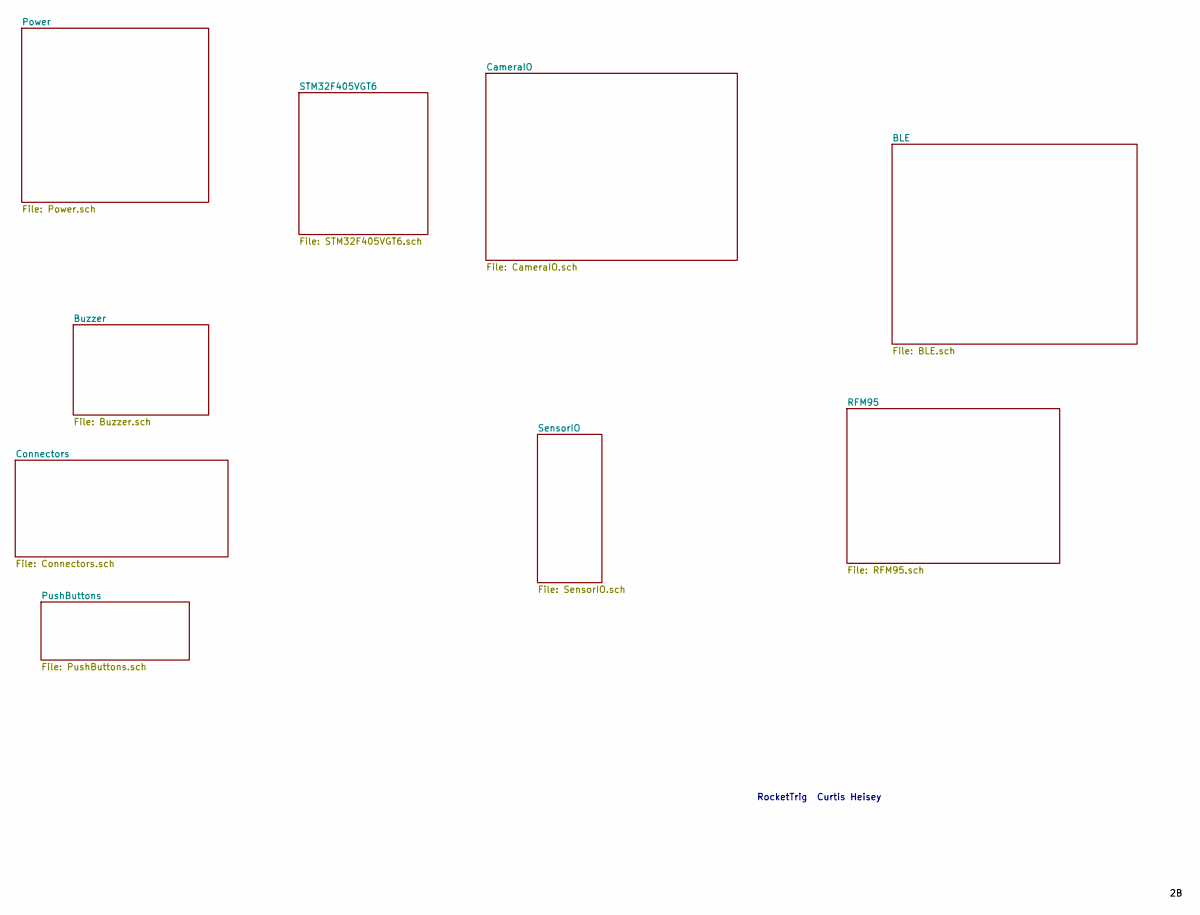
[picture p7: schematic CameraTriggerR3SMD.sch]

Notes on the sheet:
RocketTrig Curtis Heisey

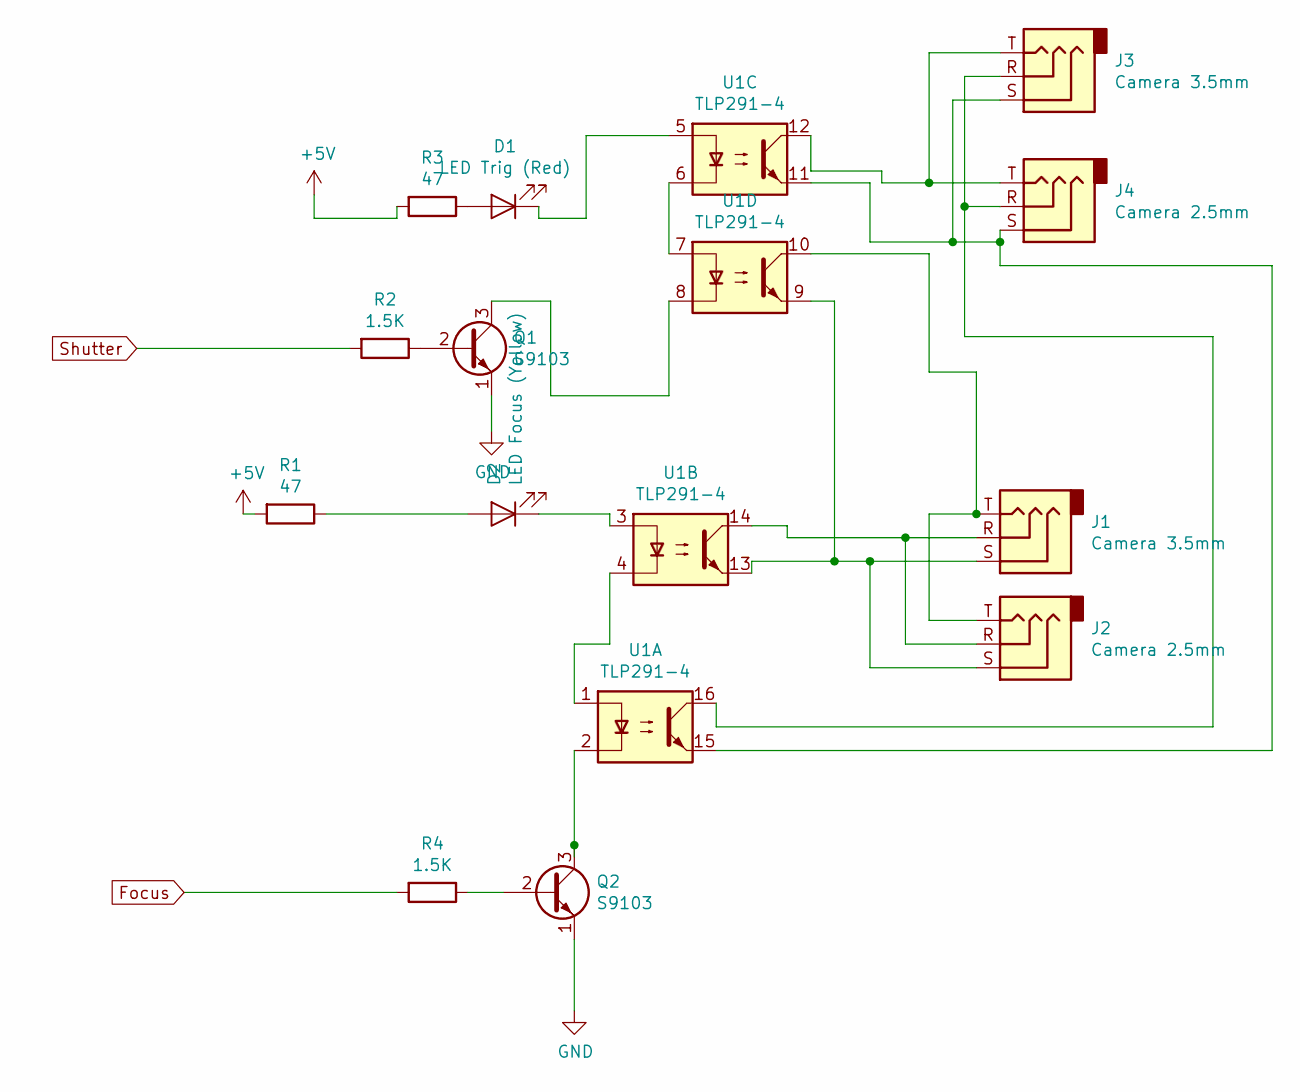
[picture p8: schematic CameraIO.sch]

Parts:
D1: LED Trig (Red); LED_0603_1608Metric; LCSC C2286
D2: LED Focus (Yellow); LED_0603_1608Metric; LCSC C72038
J1, J3: Camera 3.5mm; Jack_3.5mm_CUI_SJ1-3533NG_Horizontal_CircularHoles
J2, J4: Camera 2.5mm; CUI_SJ1-2503A
Q1, Q2: S9103; SOT-23; LCSC C6749
R1, R3: 47; R_0402_1005Metric; LCSC C25118
R2, R4: 1.5K; R_0603_1608Metric; LCSC C22843
U1: TLP291-4; SOIC-16_4.55x10.3mm_P1.27mm; LCSC C60900

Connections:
+5V: R1.2, R3.2; also elsewhere on the board
Focus: R4.2; also elsewhere on the board
GND: Q1.1 (E), Q2.1 (E); also elsewhere on the board
unnamed: D1.1 (K), U1.5
unnamed: D1.2 (A), R3.1
unnamed: D2.1 (K), U1.3
unnamed: D2.2 (A), R1.1
unnamed: J1.R, J2.R, U1.14
unnamed: J1.S, J2.S, U1.9, U1.13
unnamed: J1.T, J2.T, U1.10
unnamed: J3.R, J4.R, U1.16
unnamed: J3.S, J4.S, U1.11, U1.15
unnamed: J3.T, J4.T, U1.12
unnamed: Q1.2 (B), R2.1
unnamed: Q1.3 (C), U1.8
unnamed: Q2.2 (B), R4.1
unnamed: Q2.3 (C), U1.2
unnamed: U1.1, U1.4
unnamed: U1.6, U1.7
Shutter: R2.2; also elsewhere on the board

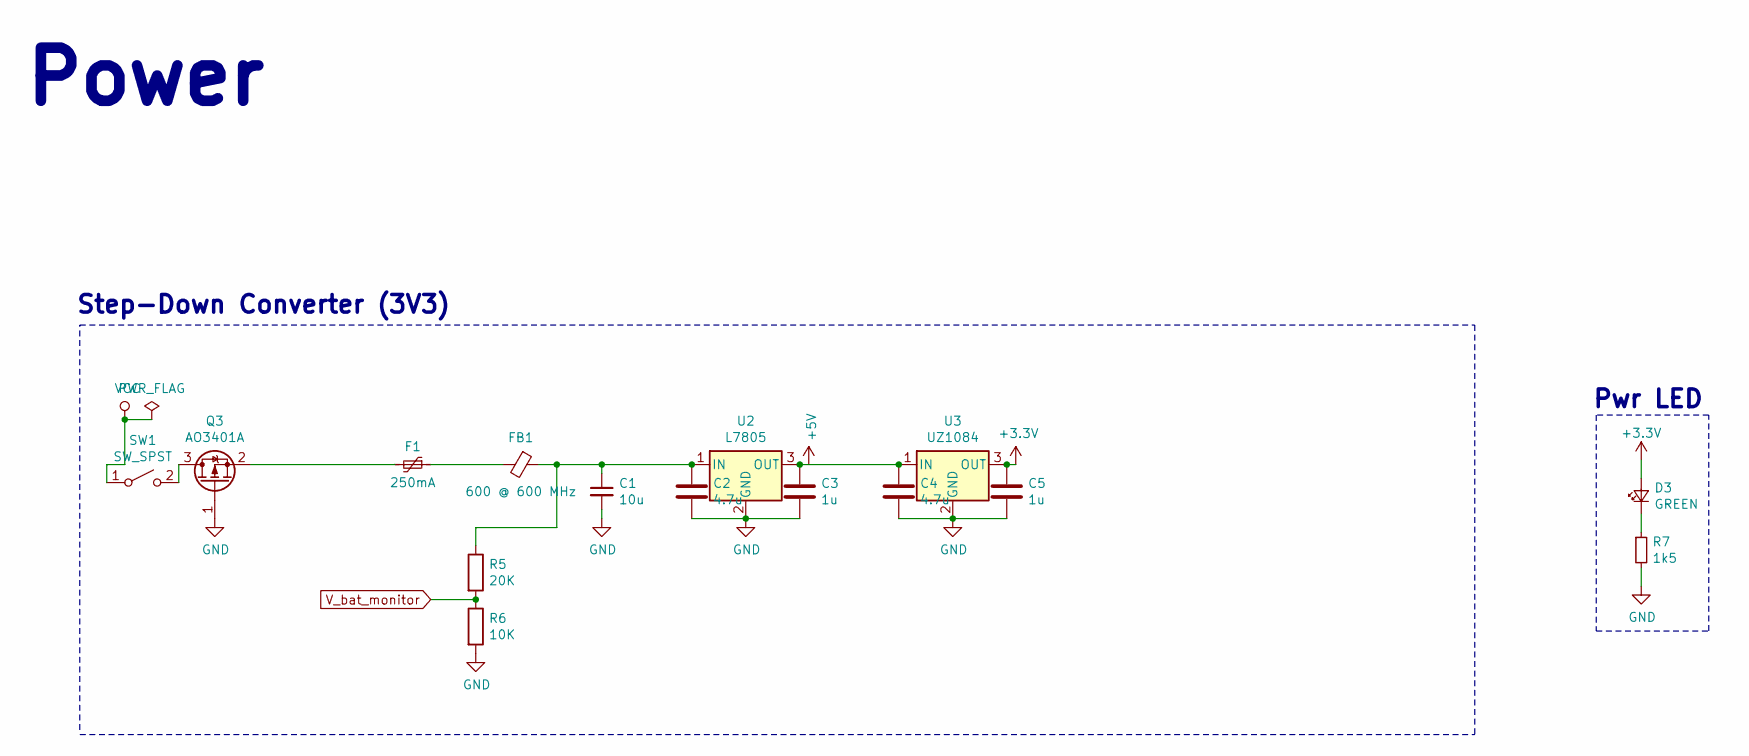
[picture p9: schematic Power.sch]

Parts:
C1: 10u; C_1206_3216Metric; LCSC C13585
C2, C4: 4.7u; C_0603_1608Metric; LCSC C19666
C3, C5: 1u; C_0402_1005Metric; LCSC C52923
D3: GREEN; LED_0603_1608Metric; LCSC C72043
F1: 250mA; Fuse_1206_3216Metric; LCSC C70068
FB1: 600 @ 600 MHz; L_0805_2012Metric; LCSC C1017
Q3: AO3401A; SOT-23; LCSC C15127
R5: 20K; R_0603_1608Metric; LCSC C4184
R6: 10K; R_0402_1005Metric; LCSC C25744
R7: 1k5; R_0603_1608Metric; LCSC C22843
SW1: SW_SPST; SW_DIP_SPSTx01_Slide_9.78x4.72mm_W7.62mm_P2.54mm
U2: L7805; TO-252-2; LCSC C310413
U3: UZ1084; TO-252-2; LCSC C84897

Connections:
+3V3: C5.1, D3.2 (A), U3.3 (OUT); also elsewhere on the board
+5V: C3.1, C4.1, U2.3 (OUT), U3.1 (IN); also elsewhere on the board
GND: C1.2, C2.2, C3.2, C4.2, C5.2, Q3.1 (G), R6.2, R7.2, U2.2 (GND), U3.2 (GND); also elsewhere on the board
unnamed: C1.1, C2.1, FB1.1, R5.1, U2.1 (IN)
unnamed: D3.1 (K), R7.1
unnamed: F1.1, FB1.2
unnamed: F1.2, Q3.2 (S)
unnamed: Q3.3 (D), SW1.2 (B)
VCC: SW1.1 (A); also elsewhere on the board
V_bat_monitor: R5.2, R6.1; also elsewhere on the board

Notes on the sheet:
Power
Step-Down Converter (3V3)
Pwr LED

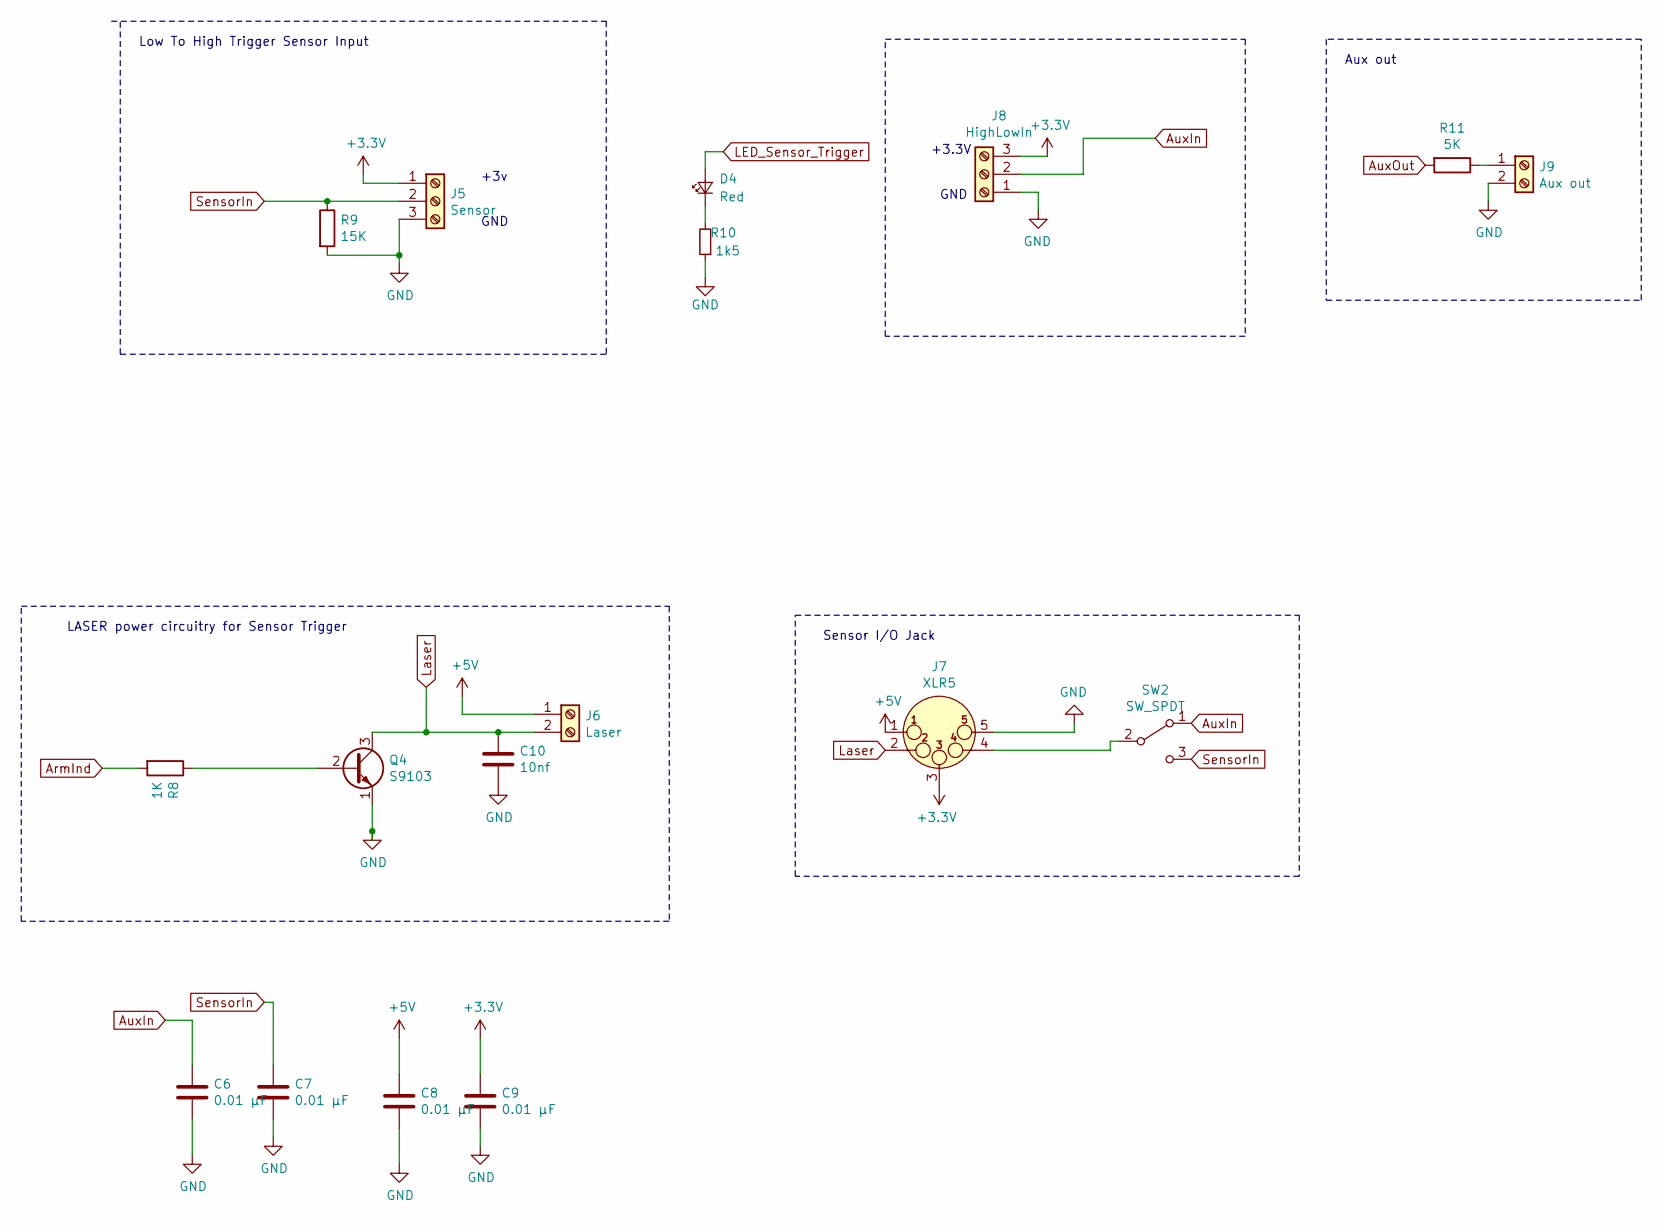
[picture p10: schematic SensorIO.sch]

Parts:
C6, C7, C8, C9: 0.01 μF; C_0402_1005Metric; LCSC C1525
C10: 10nf; C_0402_1005Metric; LCSC C15195
D4: Red; LED_0603_1608Metric; LCSC C2286
J5: Sensor; TerminalBlock_TE_282834-3_1x03_P2.54mm_Horizontal
J6: Laser; TerminalBlock_TE_282834-2_1x02_P2.54mm_Horizontal
J7: XLR5; Jack_XLR_Neutrik_NC5MBH_Horizontal
J8: HighLowIn; TerminalBlock_TE_282834-3_1x03_P2.54mm_Horizontal
J9: Aux out; TerminalBlock_TE_282834-2_1x02_P2.54mm_Horizontal
Q4: S9103; SOT-23; LCSC C6749
R8: 1K; R_0603_1608Metric; LCSC C21190
R9: 15K; R_0603_1608Metric; LCSC C22809
R10: 1k5; R_0603_1608Metric; LCSC C22843
R11: 5K; R_0402_1005Metric; LCSC C25744
SW2: SW_SPDT; SW_Slide_1P2T_CK_OS102011MS2Q

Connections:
+3V3: C9.1, J5.1, J7.3, J8.3; also elsewhere on the board
+5V: C8.1, J6.1, J7.1; also elsewhere on the board
ArmInd: R8.2; also elsewhere on the board
AuxIn: C6.1, J8.2, SW2.1 (A); also elsewhere on the board
AuxOut: R11.2; also elsewhere on the board
GND: C6.2, C7.2, C8.2, C9.2, C10.2, J5.3, J7.5, J8.1, J9.2, Q4.1 (E), R9.2, R10.1; also elsewhere on the board
LED_Sensor_Trigger: D4.2 (A); also elsewhere on the board
Laser: C10.1, J6.2, J7.2, Q4.3 (C)
unnamed: D4.1 (K), R10.2
unnamed: J7.4 (P3), SW2.2 (B)
unnamed: J9.1, R11.1
unnamed: Q4.2 (B), R8.1
SensorIn: C7.1, J5.2, R9.1, SW2.3 (C); also elsewhere on the board

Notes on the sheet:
+3v
GND
+3.3V
Low To High Trigger Sensor Input
Aux out
Sensor I/O Jack
LASER power circuitry for Sensor Trigger

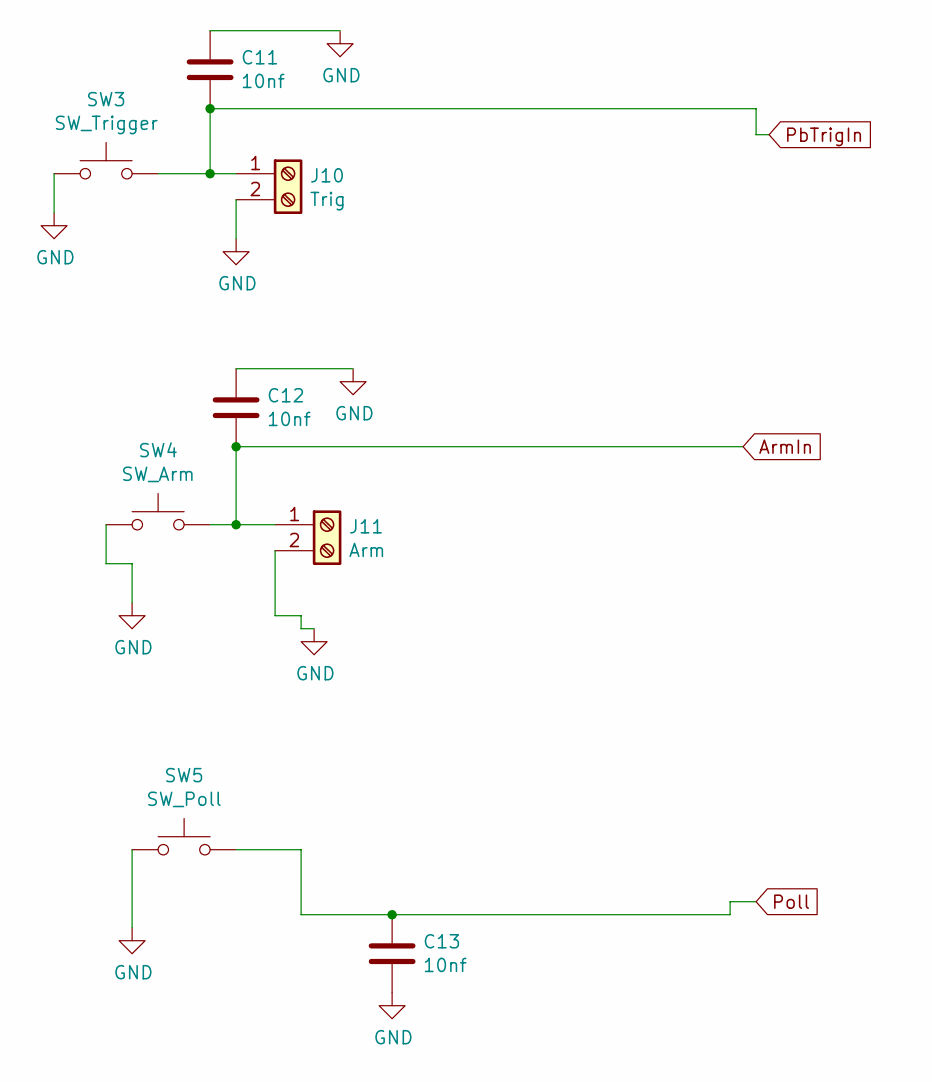
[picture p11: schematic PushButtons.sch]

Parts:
C11, C12, C13: 10nf; C_0402_1005Metric; LCSC C15195
J10: Trig; TerminalBlock_TE_282834-2_1x02_P2.54mm_Horizontal
J11: Arm; TerminalBlock_TE_282834-2_1x02_P2.54mm_Horizontal
SW3: SW_Trigger; KSA_Tactile_SPST; LCSC C127509
SW4: SW_Arm; KSA_Tactile_SPST; LCSC C127509
SW5: SW_Poll; KSA_Tactile_SPST; LCSC C127509

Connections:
ArmIn: C12.2, J11.1, SW4.2; also elsewhere on the board
GND: C11.1, C12.1, C13.2, J10.2, J11.2, SW3.1, SW4.1, SW5.1; also elsewhere on the board
PbTrigIn: C11.2, J10.1, SW3.2; also elsewhere on the board
Poll: C13.1, SW5.2; also elsewhere on the board

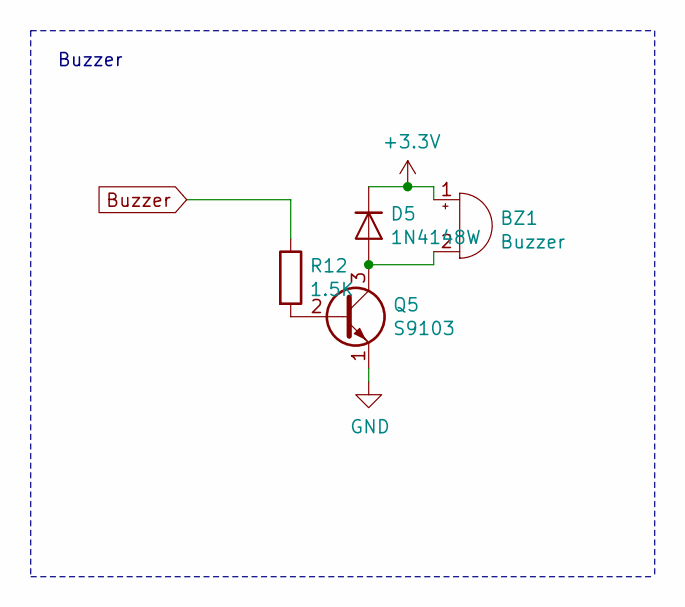
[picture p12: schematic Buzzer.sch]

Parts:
BZ1: Buzzer; Buzzer_TDK_PS1240P02BT_D12.2mm_H6.5mm
D5: 1N4148W; D_SOD-323F; LCSC C2128
Q5: S9103; SOT-23; LCSC C6749
R12: 1.5K; R_0603_1608Metric; LCSC C22843

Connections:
+3V3: BZ1.1 (-), D5.1 (K); also elsewhere on the board
Buzzer: R12.1; also elsewhere on the board
GND: Q5.1 (E); also elsewhere on the board
unnamed: BZ1.2 (+), D5.2 (A), Q5.3 (C)
unnamed: Q5.2 (B), R12.2

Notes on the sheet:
Buzzer

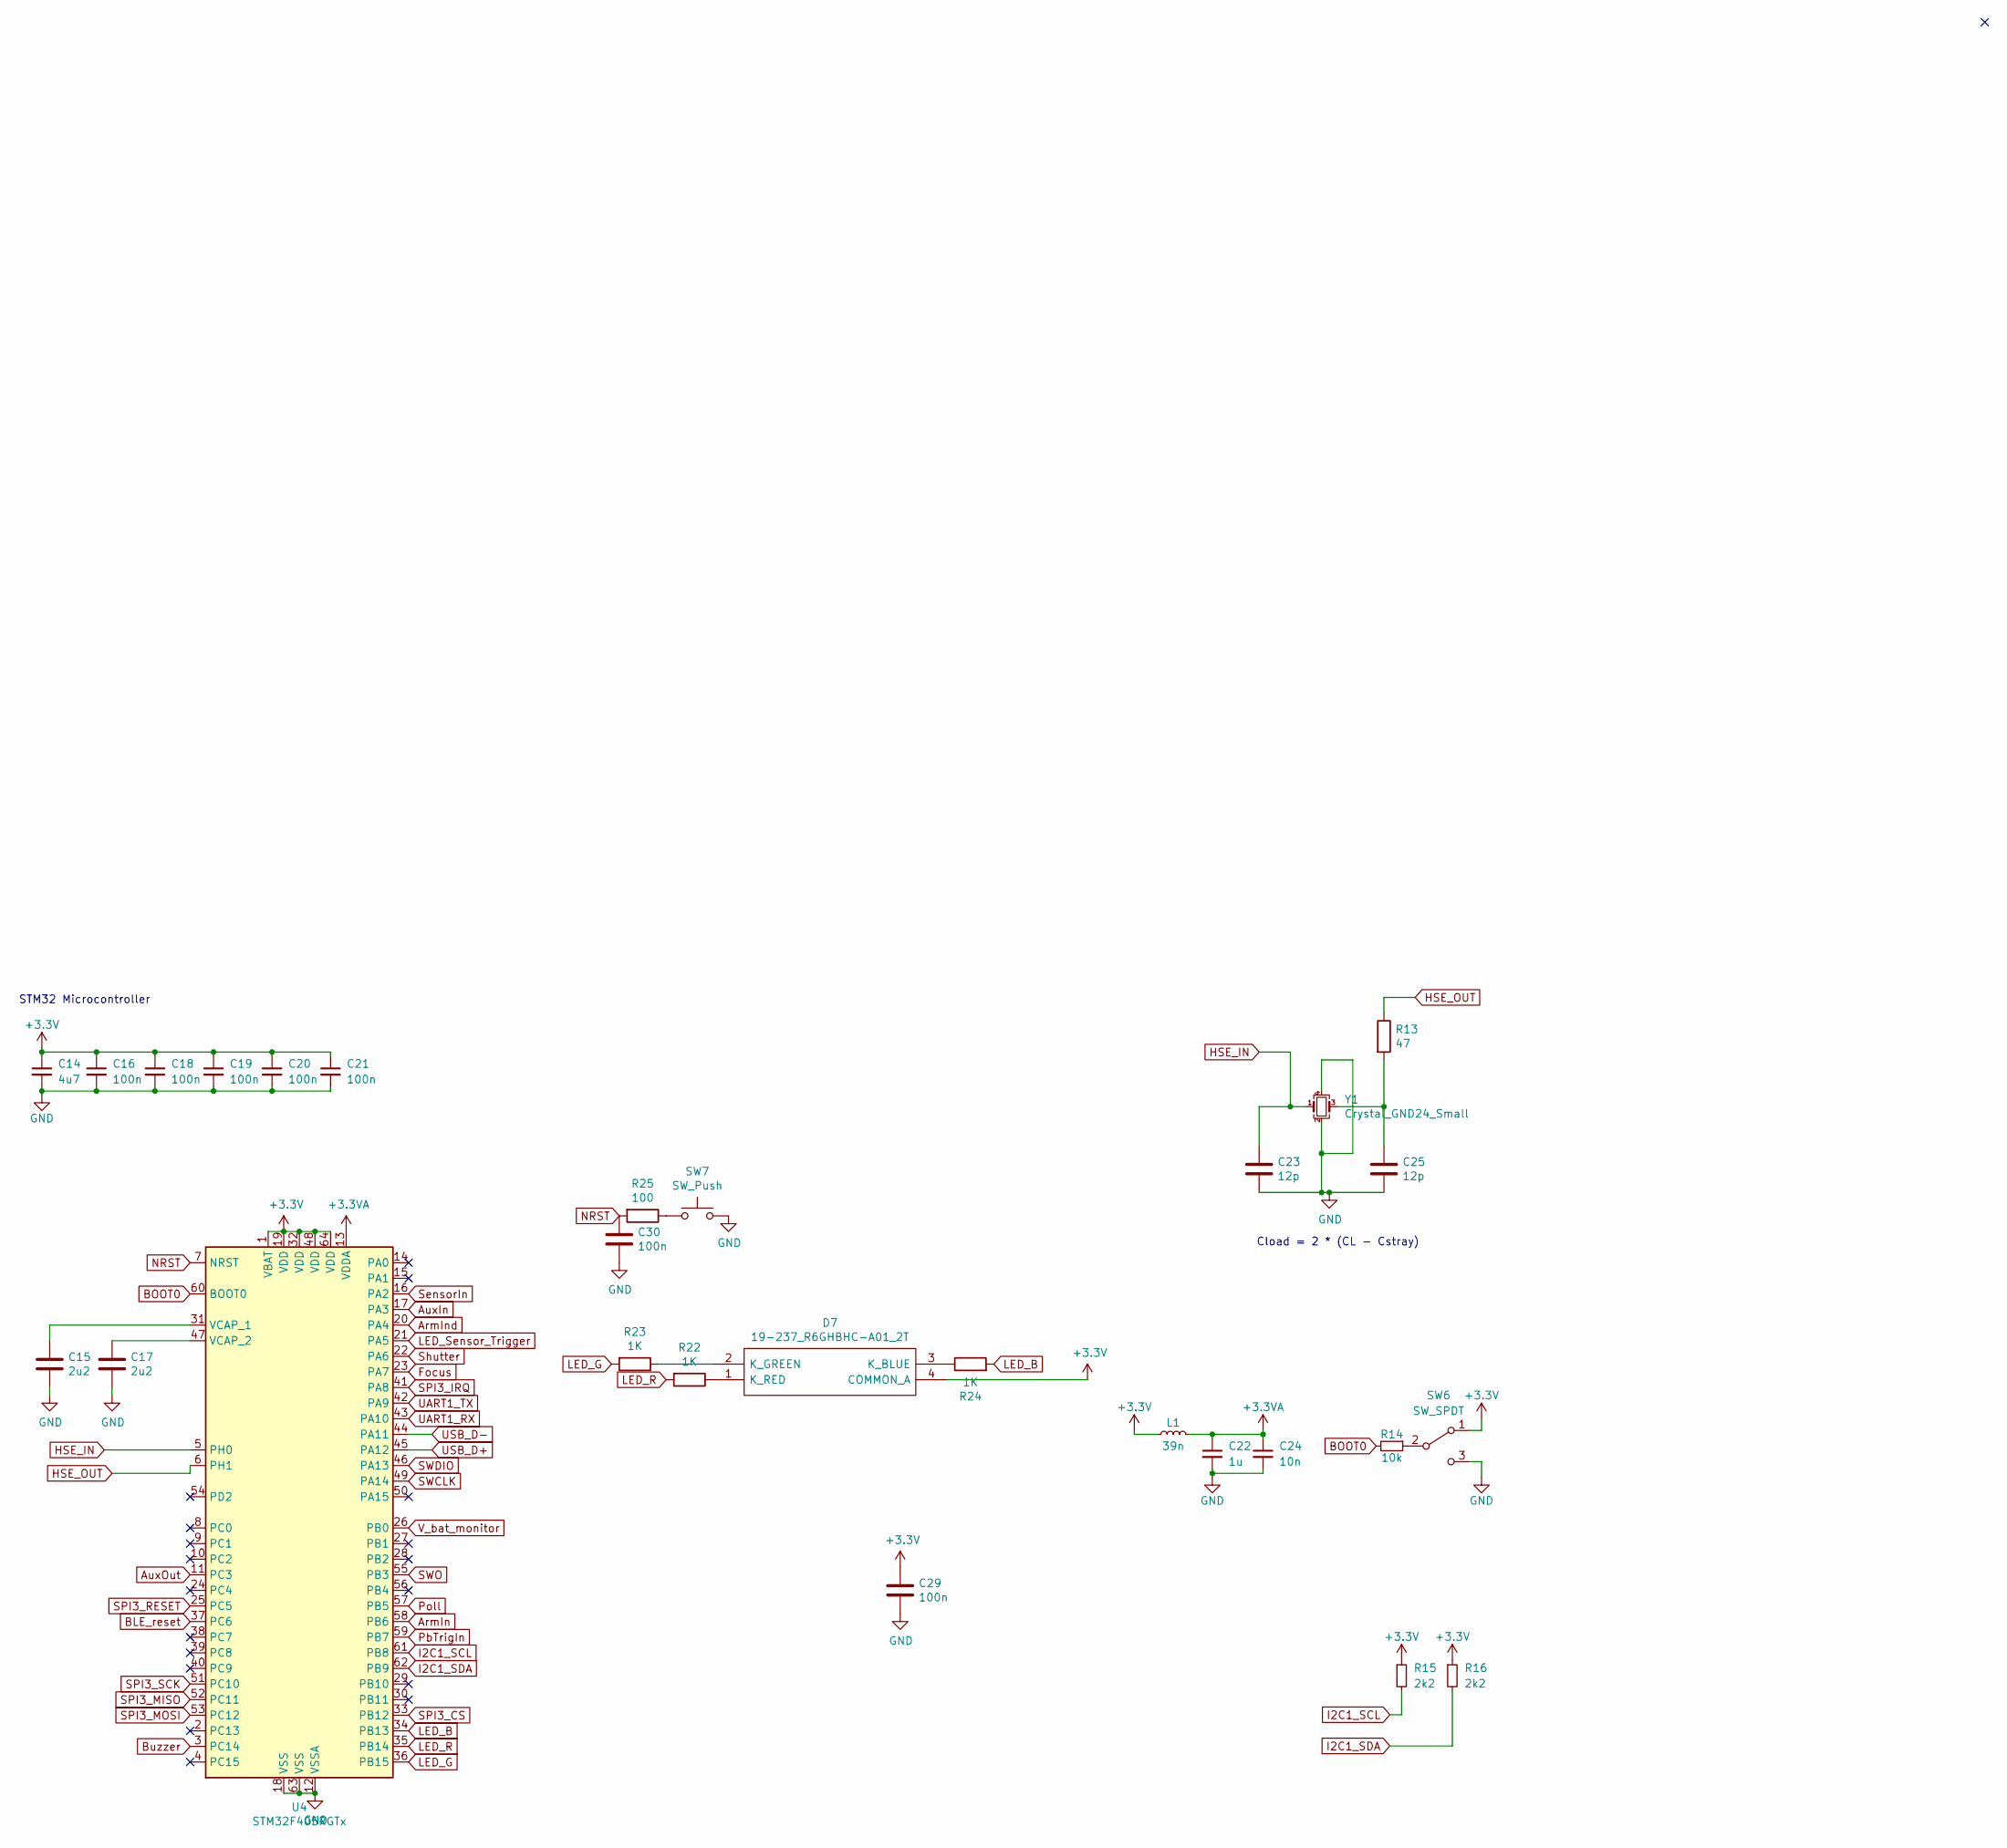
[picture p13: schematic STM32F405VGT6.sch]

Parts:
C14: 4u7; C_0603_1608Metric; LCSC C19666
C15, C17: 2u2; C_0603_1608Metric; LCSC C23630
C16, C18, C19, C20, C21: 100n; C_0402_1005Metric; LCSC C1525
C22: 1u; C_0402_1005Metric; LCSC C52923
C23, C25: 12p; C_0402_1005Metric; LCSC C1547
C24: 10n; C_0402_1005Metric; LCSC C15195
C29, C30: 100n; C_0402_1005Metric
D7: 19-237_R6GHBHC-A01_2T; 19237R6GHBHCA012T; Manufacturer_Part_Number 19-237/R6GHBHC-A01/2T; LCSC C60105
L1: 39n; L_0402_1005Metric; LCSC C26443
R13: 47; R_0402_1005Metric; LCSC C25118
R14: 10k; R_0402_1005Metric; LCSC C25744
R15, R16: 2k2; R_0402_1005Metric; LCSC C25879
R22, R23, R24: 1K; R_0402_1005Metric; LCSC C11702
R25: 100; R_0603_1608Metric; LCSC C22775
SW6: SW_SPDT; SW_SPDT_PCM12
SW7: SW_Push; SW_SPST_CK_KXT3
U4: STM32F405RGTx; LQFP-64_10x10mm_P0.5mm; LCSC C15742
Y1: Crystal_GND24_Small; Crystal_SMD_3225-4Pin_3.2x2.5mm; LCSC C13738

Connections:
+3.3VA: C22.1, C24.1, L1.2, U4.13 (VDDA)
+3V3: C14.1, C16.1, C18.1, C19.1, C20.1, C21.1, C29.1, D7.4 (COMMON_A), L1.1, R15.1, R16.1, SW6.1 (A), U4.1 (VBAT), U4.19 (VDD), U4.32 (VDD), U4.48 (VDD), U4.64 (VDD); also elsewhere on the board
ArmIn: U4.58 (PB6); also elsewhere on the board
ArmInd: U4.20 (PA4); also elsewhere on the board
AuxIn: U4.17 (PA3); also elsewhere on the board
AuxOut: U4.11 (PC3); also elsewhere on the board
BLE_reset: U4.37 (PC6); also elsewhere on the board
BOOT0: R14.2, U4.60 (BOOT0)
Buzzer: U4.3 (PC14); also elsewhere on the board
Focus: U4.23 (PA7); also elsewhere on the board
GND: C14.2, C15.2, C16.2, C17.2, C18.2, C19.2, C20.2, C21.2, C22.2, C23.2, C24.2, C25.2, C29.2, C30.2, SW6.3 (C), SW7.2, U4.12 (VSSA), U4.18 (VSS), U4.63 (VSS), Y1.2, Y1.4; also elsewhere on the board
HSE_IN: C23.1, U4.5 (PH0), Y1.1
HSE_OUT: R13.1, U4.6 (PH1)
I2C1_SCL: R15.2, U4.61 (PB8); also elsewhere on the board
I2C1_SDA: R16.2, U4.62 (PB9); also elsewhere on the board
LED_B: R24.2, U4.34 (PB13)
LED_G: R23.2, U4.36 (PB15)
LED_R: R22.2, U4.35 (PB14)
LED_Sensor_Trigger: U4.21 (PA5); also elsewhere on the board
NRST: C30.1, R25.2, U4.7 (NRST); also elsewhere on the board
unnamed: C15.1, U4.31 (VCAP_1)
unnamed: C17.1, U4.47 (VCAP_2)
unnamed: C25.1, R13.2, Y1.3
unnamed: D7.1 (K_RED), R22.1
unnamed: D7.2 (K_GREEN), R23.1
unnamed: D7.3 (K_BLUE), R24.1
unnamed: R14.1, SW6.2 (B)
unnamed: R25.1, SW7.1
PbTrigIn: U4.59 (PB7); also elsewhere on the board
Poll: U4.57 (PB5); also elsewhere on the board
SPI3_CS: U4.33 (PB12); also elsewhere on the board
SPI3_IRQ: U4.41 (PA8); also elsewhere on the board
SPI3_MISO: U4.52 (PC11); also elsewhere on the board
SPI3_MOSI: U4.53 (PC12); also elsewhere on the board
SPI3_RESET: U4.25 (PC5); also elsewhere on the board
SPI3_SCK: U4.51 (PC10); also elsewhere on the board
SWCLK: U4.49 (PA14); also elsewhere on the board
SWDIO: U4.46 (PA13); also elsewhere on the board
SWO: U4.55 (PB3); also elsewhere on the board
SensorIn: U4.16 (PA2); also elsewhere on the board
Shutter: U4.22 (PA6); also elsewhere on the board
UART1_RX: U4.43 (PA10); also elsewhere on the board
UART1_TX: U4.42 (PA9); also elsewhere on the board
USB_D+: U4.45 (PA12); also elsewhere on the board
USB_D-: U4.44 (PA11); also elsewhere on the board
V_bat_monitor: U4.26 (PB0); also elsewhere on the board

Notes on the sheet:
Cload = 2 * (CL - Cstray)
STM32 Microcontroller

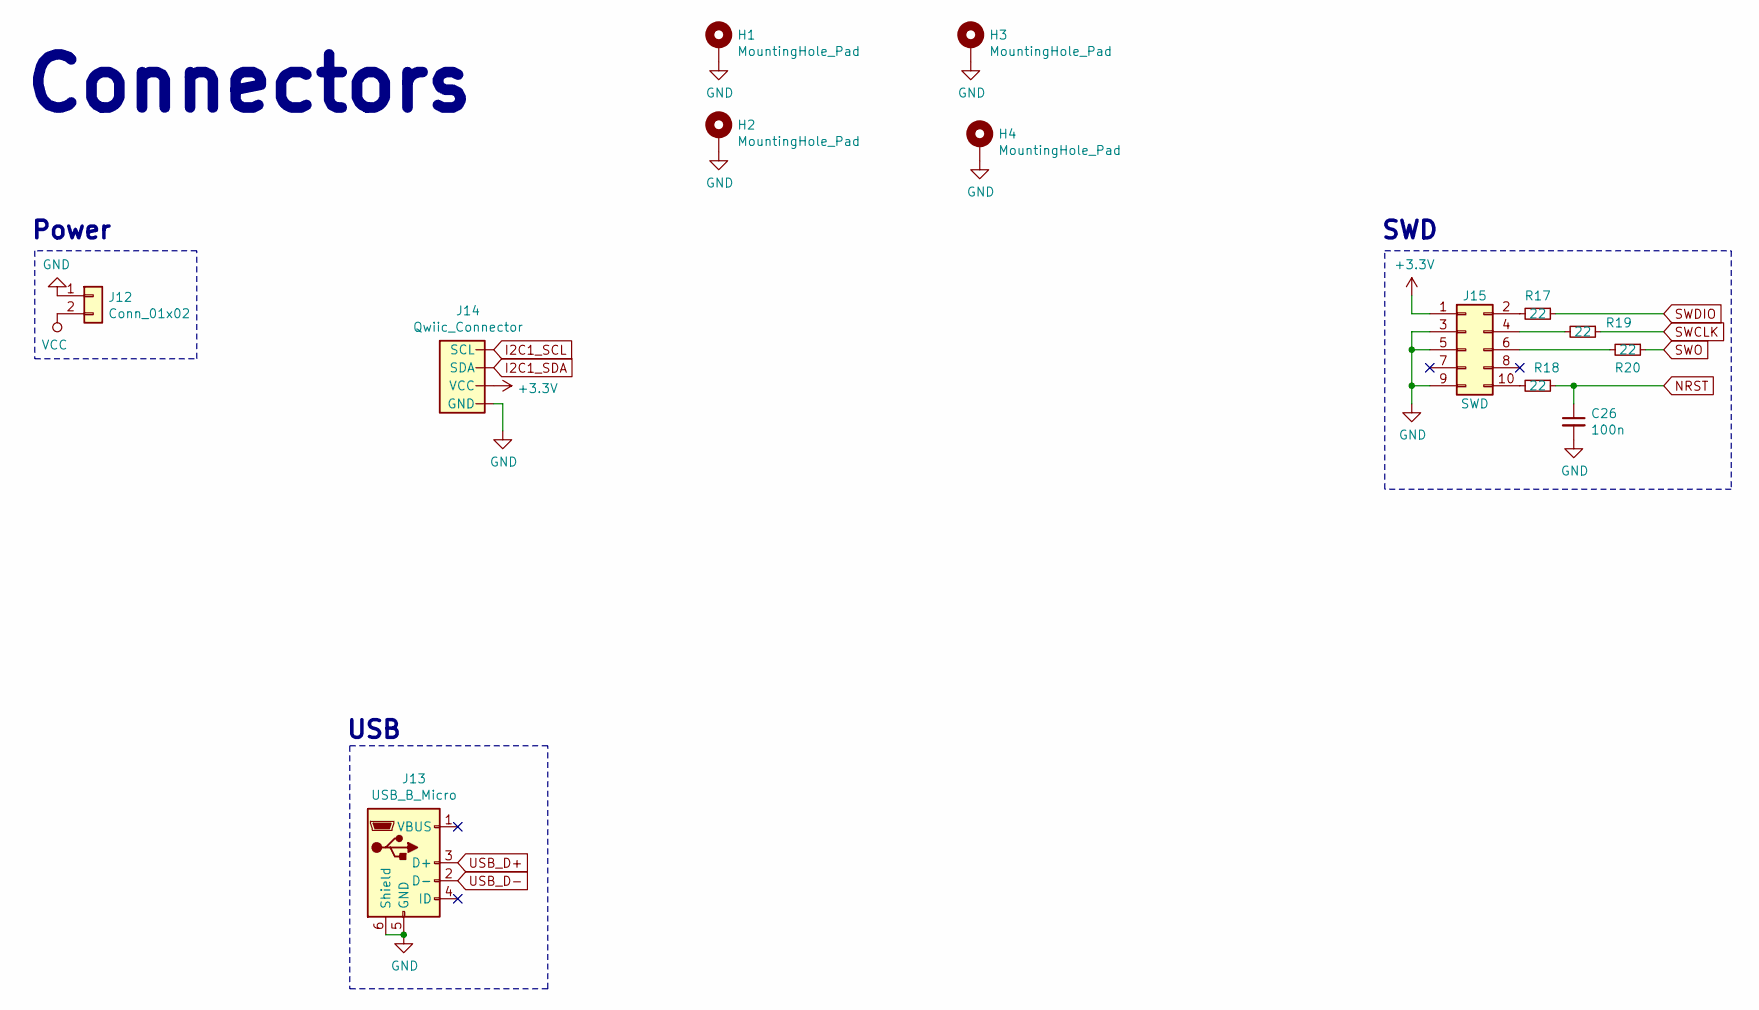
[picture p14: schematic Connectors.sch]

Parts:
C26: 100n; C_0402_1005Metric; LCSC C1525
H1, H2, H3, H4: MountingHole_Pad; MountingHole_3.2mm_M3_Pad_Via
J12: Conn_01x02; AMASS_XT30U-F_1x02_P5.0mm_Vertical
J13: USB_B_Micro; USB_Micro-B_Wuerth_629105150521
J14: Qwiic_Connector; 1X04_1MM_RA_STRESSRELIEF
J15: SWD; PinHeader_2x05_P1.27mm_Vertical_SMD
R17, R18, R19, R20: 22; R_0402_1005Metric; LCSC C25092

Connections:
+3V3: J14.2 (VCC), J15.1; also elsewhere on the board
GND: C26.2, H1.1, H2.1, H3.1, H4.1, J12.1, J13.5 (GND), J13.6 (Shield), J14.1 (GND), J15.3, J15.5, J15.9; also elsewhere on the board
I2C1_SCL: J14.4 (SCL); also elsewhere on the board
I2C1_SDA: J14.3 (SDA); also elsewhere on the board
NRST: C26.1, R18.1; also elsewhere on the board
unnamed: J15.2, R17.2
unnamed: J15.4, R19.2
unnamed: J15.6, R20.2
unnamed: J15.10, R18.2
SWCLK: R19.1; also elsewhere on the board
SWDIO: R17.1; also elsewhere on the board
SWO: R20.1; also elsewhere on the board
USB_D+: J13.3 (D+); also elsewhere on the board
USB_D-: J13.2 (D-); also elsewhere on the board
VCC: J12.2; also elsewhere on the board

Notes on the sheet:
Connectors
USB
Power
SWD

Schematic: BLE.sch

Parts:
C27: 100n; C_0402_1005Metric; LCSC C1525
D6: BLUE; LED_0603_1608Metric; LCSC C72041
R21: 1k5; R_0603_1608Metric; LCSC C22843
U5: RN4871; Microchip_RN4871

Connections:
+3V3: C27.1, U5.14 (VBAT); also elsewhere on the board
BLE_reset: U5.10 (RST); also elsewhere on the board
GND: C27.2, R21.1, U5.2 (GND), U5.13 (GND); also elsewhere on the board
LED_TXRX: D6.2 (A), U5.11 (P0_0)
unnamed: D6.1 (K), R21.2
UART1_RX: U5.8 (UART_TX); also elsewhere on the board
UART1_TX: U5.7 (UART_RX); also elsewhere on the board

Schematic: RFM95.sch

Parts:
C28: 10nf; C_0402_1005Metric; Partno C0805C103J4HACTU; LCSC C15195
J16: Conn_Coaxial; SMA_Amphenol_132289_EdgeMount; Partno 132289
U6: RFM95W-915S2; HOPERF_RFM9XW_THT

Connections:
+3V3: C28.1, U6.13 (3.3V); also elsewhere on the board
GND: C28.2, J16.2 (Ext), U6.1 (GND), U6.8 (GND), U6.10 (GND); also elsewhere on the board
unnamed: J16.1 (In), U6.9 (ANT)
SPI3_CS: U6.5 (NSS); also elsewhere on the board
SPI3_IRQ: U6.14 (DIO0); also elsewhere on the board
SPI3_MISO: U6.2 (MISO); also elsewhere on the board
SPI3_MOSI: U6.3 (MOSI); also elsewhere on the board
SPI3_RESET: U6.6 (RESET); also elsewhere on the board
SPI3_SCK: U6.4 (SCK); also elsewhere on the board

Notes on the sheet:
LoRa 'Radio using RFM95 Based on Feather M0 LoRa Adafruit 3178

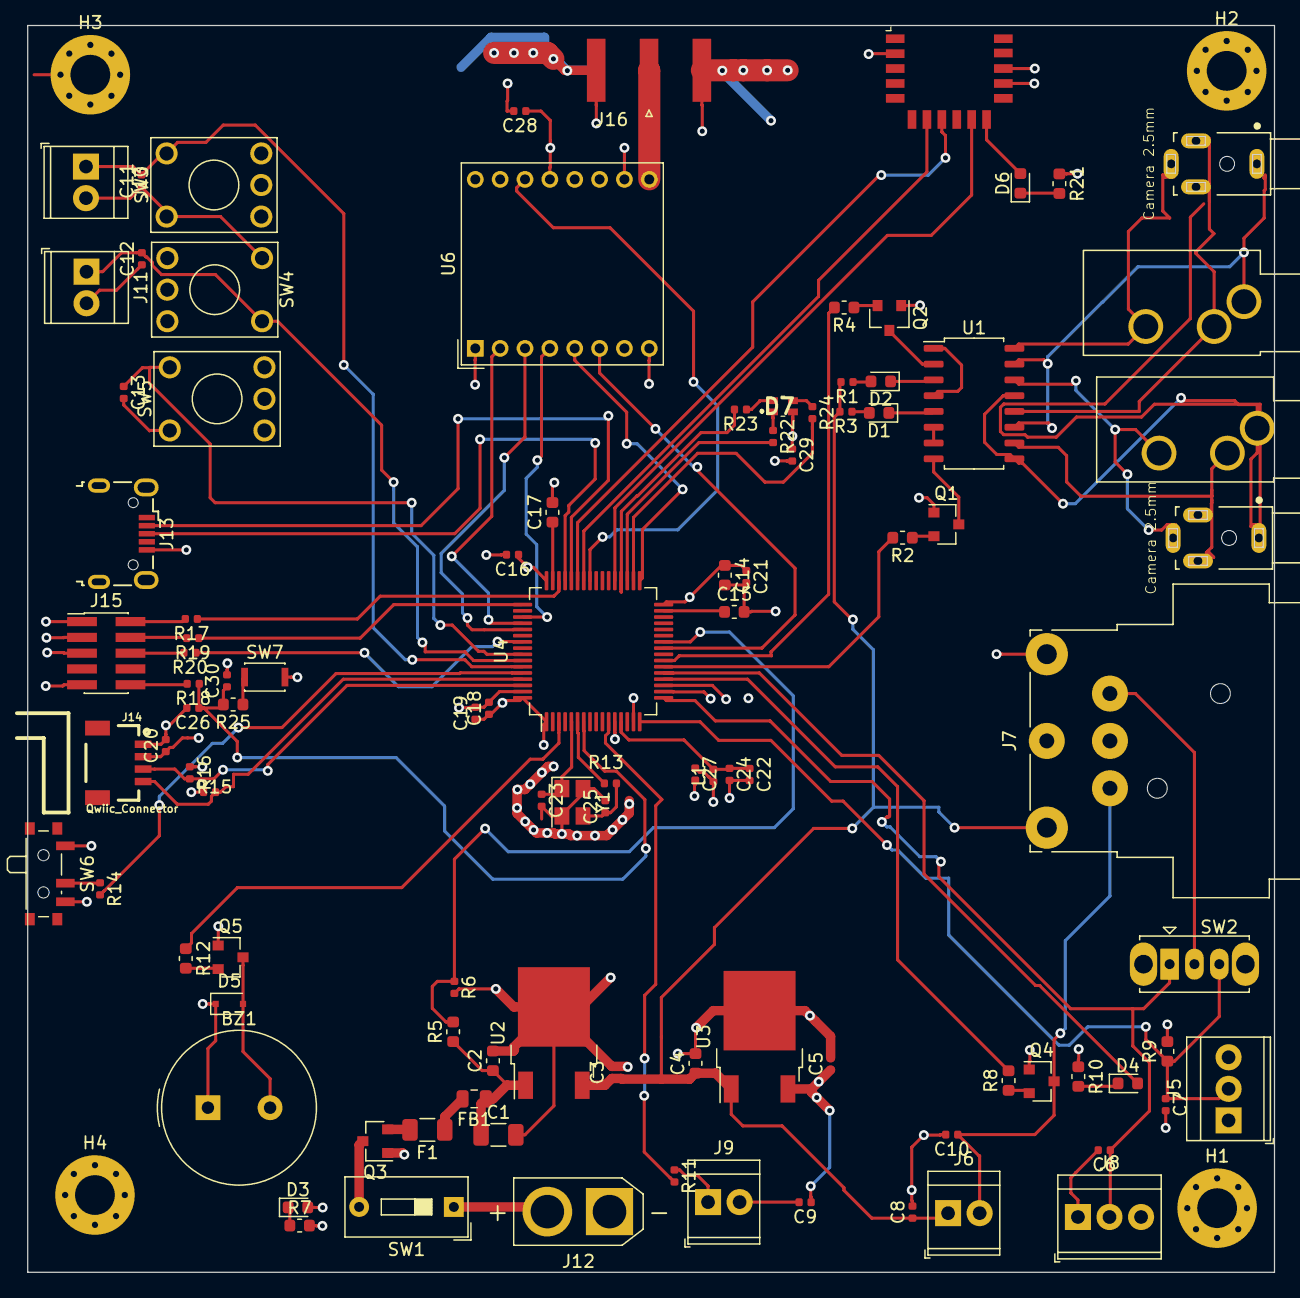
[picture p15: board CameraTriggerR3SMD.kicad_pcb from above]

Board: 4 copper layers, 100.3 x 100.3 mm, 105 parts (0 on the bottom side), 83 nets.

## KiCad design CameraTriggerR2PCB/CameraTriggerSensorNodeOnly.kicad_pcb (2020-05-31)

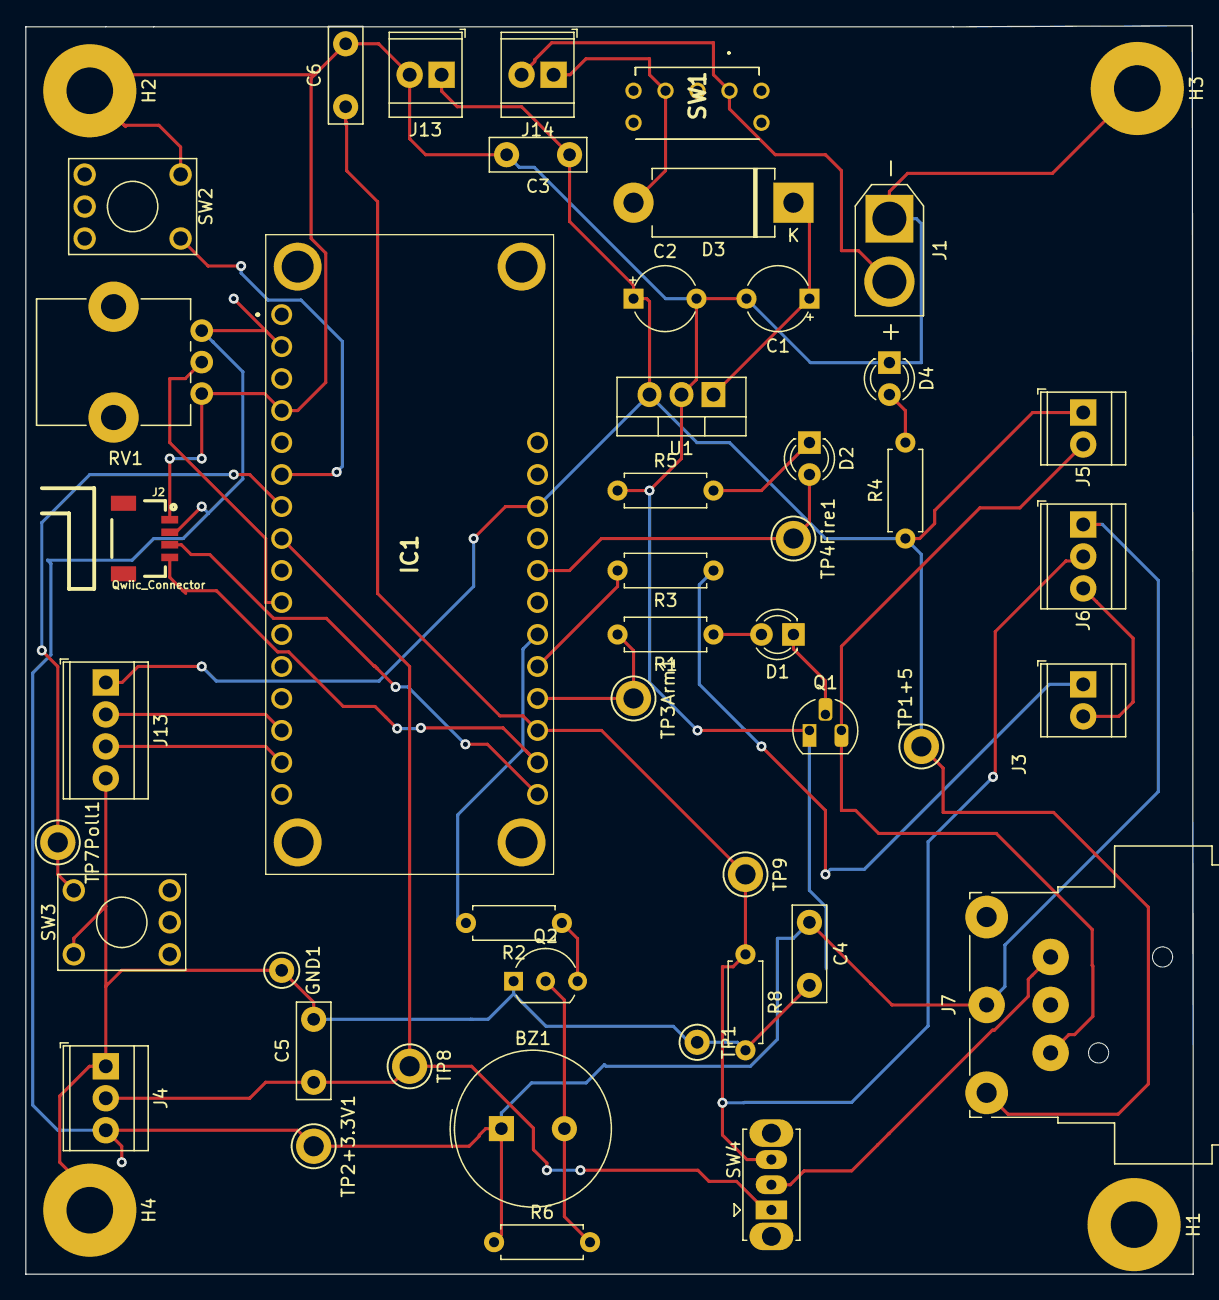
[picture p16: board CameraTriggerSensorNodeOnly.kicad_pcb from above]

Board: 2 copper layers, 92.7 x 99.1 mm, 50 parts (0 on the bottom side), 28 nets.

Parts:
BZ1: Buzzer; Buzzer_TDK_PS1240P02BT_D12.2mm_H6.5mm
C1: 25uf; CP_Radial_Tantal_D5.0mm_P5.00mm
C2: 0.1uf; CP_Radial_Tantal_D5.0mm_P5.00mm
C3, C4, C5, C6: 0.01 μF; C_Disc_D7.5mm_W2.5mm_P5.00mm
D1: LED Arm; LED_D3.0mm
D2: LED Trig; LED_D3.0mm
D3: D; D_DO-201AD_P12.70mm_Horizontal
D4: PWR; LED_D3.0mm
GND1: TestPoint; TestPoint_Keystone_5000-5004_Miniature
H1, H2, H3, H4: MountingHole_3.7mm_Pad
IC1: 3178
J1: Power; AMASS_XT30U-F_1x02_P5.0mm_Vertical
J2: Qwiic_Connector; 1X04_1MM_RA_STRESSRELIEF
J3: Aux out; TerminalBlock_TE_282834-2_1x02_P2.54mm_Horizontal
J4: HighLowIn; TerminalBlock_TE_282834-3_1x03_P2.54mm_Horizontal
J5: Laser; TerminalBlock_TE_282834-2_1x02_P2.54mm_Horizontal
J6: Sensor; TerminalBlock_TE_282834-3_1x03_P2.54mm_Horizontal
J7: XLR5; Jack_XLR_Neutrik_NC5MBH_Horizontal
J13: Serial; TerminalBlock_TE_282834-4_1x04_P2.54mm_Horizontal
J13#2: +5V Always on; TerminalBlock_TE_282834-2_1x02_P2.54mm_Horizontal
J14: Ext power switch; TerminalBlock_TE_282834-2_1x02_P2.54mm_Horizontal
Q1: PN2222A; TO-92L_HandSolder
Q2: KSC1815YTA; TO-92L_Inline_Wide
R1, R2, R5, R6: 1K; R_Axial_DIN0207_L6.3mm_D2.5mm_P7.62mm_Horizontal
R3: 5K; R_Axial_DIN0207_L6.3mm_D2.5mm_P7.62mm_Horizontal
R4: 220; R_Axial_DIN0207_L6.3mm_D2.5mm_P7.62mm_Horizontal
R8: 15K; R_Axial_DIN0207_L6.3mm_D2.5mm_P7.62mm_Horizontal
RV1: 1K; Potentiometer_Alps_RK09K_Single_Vertical
SW1: AS11CB
SW2: SW_Arm; KSA_Tactile_SPST
SW3: SW_Poll; KSA_Tactile_SPST
SW4: SW_SPDT; SW_Slide_1P2T_CK_OS102011MS2Q
TP1: Gnd; TestPoint_Keystone_5000-5004_Miniature
TP1+5: +5V; TestPoint_Keystone_5010-5014_Multipurpose
TP2+3.3V1: +3.3V; TestPoint_Keystone_5010-5014_Multipurpose
TP3Arm1: Arm; TestPoint_Keystone_5010-5014_Multipurpose
TP4Fire1: Fire; TestPoint_Keystone_5010-5014_Multipurpose
TP7Poll1: Poll; TestPoint_Keystone_5010-5014_Multipurpose
TP8: HighLowIn; TestPoint_Keystone_5010-5014_Multipurpose
TP9: LowHighIn; TestPoint_Keystone_5010-5014_Multipurpose
U1: LM7805_TO220; TO-220-3_Vertical

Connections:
+3V3: BZ1.1, C4.1, IC1.27, J2.2, J4.3, J6.1, J7.3, R6.1, RV1.1, TP2+3.3V1.1
+5V: C2.1, C3.1, IC1.3, J5.1, J7.1, J13.1, J13#2.1, R4.1, TP1+5.1, U1.3
+7.5V: J1.2, J14.2, SW1.1
ArmIn: IC1.23, SW2.2
ArmInd: IC1.9, R1.2, TP3Arm1.1
AuxIn: C5.1, IC1.21, J4.2, SW4.1, TP8.1
AuxOut: IC1.8, R3.2
Buzzer: IC1.7, R2.2
GND: C1.2, C2.2, C3.2, C4.2, C5.2, C6.2, D4.1, GND1.1, H1.1, H2.1, H3.1, H4.1, IC1.25, J1.1, J2.1, J3.2, J4.1, J6.3, J7.5, J13.4, J13#2.2, Q1.1, Q2.1, R5.1, R8.2, RV1.3, SW2.1, SW3.1, TP1.1, U1.2
Laser: J5.2, J7.2, Q1.3
unnamed: BZ1.2, Q2.2, R6.2
unnamed: C1.1, D3.1, U1.1
unnamed: D1.1, Q1.2
unnamed: D1.2, R1.1
unnamed: D2.1, R5.2
unnamed: D3.2, J14.1, SW1.3
unnamed: D4.2, R4.2
unnamed: J3.1, R3.1
unnamed: J7.4, SW4.2
unnamed: Q2.3, R2.1
Poll: IC1.22, SW3.2, TP7Poll1.1
Rx_serial: IC1.15, J13.2
SCL_qwiic: IC1.11, J2.4
SDA_qwiic: IC1.12, J2.3
SensorIn: C6.1, IC1.10, J6.2, R8.1, SW4.3, TP9.1
Shutter: D2.2, IC1.5, TP4Fire1.1
Threshold: IC1.19, RV1.2
Tx_serial: IC1.14, J13.3

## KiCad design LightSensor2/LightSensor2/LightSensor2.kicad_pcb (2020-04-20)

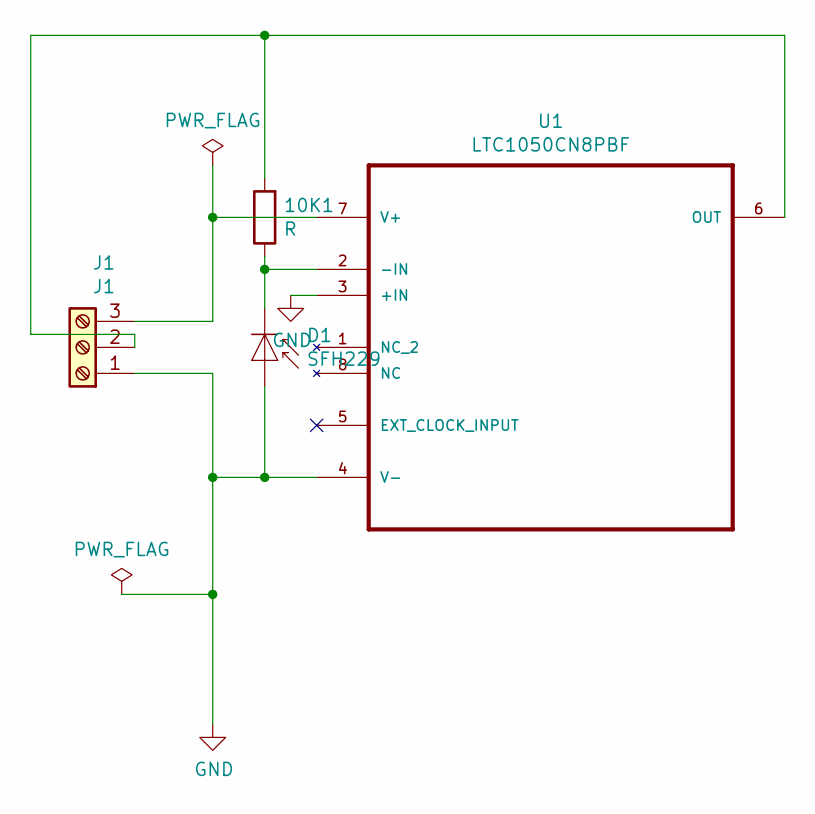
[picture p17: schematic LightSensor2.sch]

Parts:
10K1: R; R_Axial_DIN0207_L6.3mm_D2.5mm_P10.16mm_Horizontal
D1: SFH229; LED_D5.0mm_IRGrey
J1: J1; TerminalBlock_TE_282834-3_1x03_P2.54mm_Horizontal
U1: LTC1050CN8PBF; DIP-8_W7.62mm_LongPads

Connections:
GND: D1.2 (A), J1.1, U1.3 (+IN), U1.4 (V-)
unnamed: 10K1.1, D1.1 (K), U1.2 (-IN)
unnamed: 10K1.2, J1.2, U1.6 (OUT)
unnamed: J1.3, U1.7 (V+)

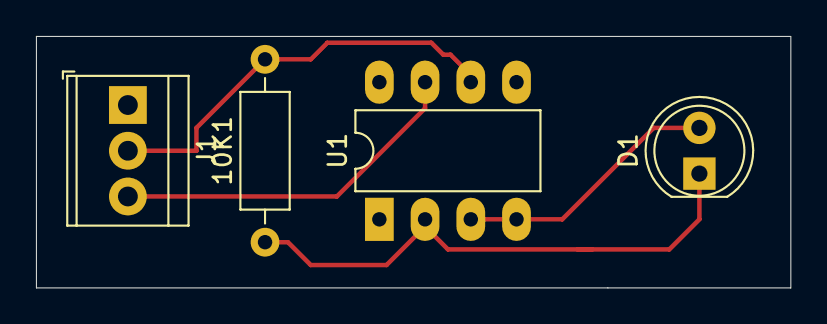
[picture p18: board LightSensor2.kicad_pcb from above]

Board: 2 copper layers, 41.9 x 14.0 mm, 4 parts (0 on the bottom side), 4 nets.

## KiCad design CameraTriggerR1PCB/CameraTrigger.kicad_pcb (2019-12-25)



Board: 2 copper layers, 99.1 x 99.1 mm, 30 parts (2 on the bottom side), 28 nets.

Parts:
BZ1: Buzzer; Buzzer_TDK_PS1240P02BT_D12.2mm_H6.5mm
C1: 25uf; CP_Radial_Tantal_D5.0mm_P5.00mm
C2: 0.1uf; CP_Radial_Tantal_D5.0mm_P5.00mm
D1: LED Arm; LED_D2.0mm_W4.8mm_H2.5mm_FlatTop
D2: LED Trig; LED_D2.0mm_W4.8mm_H2.5mm_FlatTop
J1: Power; TerminalBlock_TE_282834-2_1x02_P2.54mm_Horizontal
J2: Camera; Jack_3.5mm_CUI_SJ1-3533NG_Horizontal_CircularHoles
J3: Aux out; TerminalBlock_TE_282834-2_1x02_P2.54mm_Horizontal
J4: Aux in; TerminalBlock_TE_282834-2_1x02_P2.54mm_Horizontal
J5: Laser; TerminalBlock_TE_282834-2_1x02_P2.54mm_Horizontal
J6: Sensor; TerminalBlock_TE_282834-3_1x03_P2.54mm_Horizontal
J7: Trig; TerminalBlock_TE_282834-2_1x02_P2.54mm_Horizontal
J8: Arm; TerminalBlock_TE_282834-2_1x02_P2.54mm_Horizontal
J9: feather long; PinHeader_1x16_P2.54mm_Vertical
J10: feather short; PinHeader_1x12_P2.54mm_Vertical
J11: Spare; TerminalBlock_TE_282834-2_1x02_P2.54mm_Horizontal
Q1: PN2222A; TO-92_Inline
R1: 1K; R_Axial_DIN0207_L6.3mm_D2.5mm_P7.62mm_Horizontal
R2, R5: 220; R_Axial_DIN0207_L6.3mm_D2.5mm_P7.62mm_Horizontal
R3, R4: 5K; R_Axial_DIN0207_L6.3mm_D2.5mm_P7.62mm_Horizontal
RV1: 10K; Potentiometer_Alps_RK09K_Single_Vertical
SW1: SW_Power; SW_DIP_SPSTx01_Slide_9.78x4.72mm_W7.62mm_P2.54mm
SW2: SW_Trigger; KSA_Tactile_SPST
SW3: SW_Poll; KSA_Tactile_SPST
SW4: SW_Arm; KSA_Tactile_SPST
U1: LM7805_TO220; TO-220-3_Vertical
U2, U3: 4N25; DIP-6_W7.62mm

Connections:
+3V3: J6.1, J9.15, RV1.1
+5V: C2.1, J5.1, J10.10, U1.3
+7.5V: J1.1, SW1.1
ArmIn: J8.1, J9.11, SW4.2
ArmInd: J10.4, R1.2
AuxIn: J4.1, J9.9
AuxOut: J10.5, R3.2
Buzzer: BZ1.1, J10.6
DelayMS: J9.8, RV1.2
Focus: J10.8, R5.2
GND: BZ1.2, C1.2, C2.2, J1.2, J3.2, J4.2, J6.3, J7.2, J8.2, J9.13, J11.2, Q1.1, RV1.3, SW2.1, SW3.1, SW4.1, U1.2, U2.2, U3.2
unnamed: C1.1, SW1.2, U1.1
unnamed: D1.1, Q1.2
unnamed: D1.2, R1.1
unnamed: D2.1, R2.2
unnamed: J2.R, U2.5
unnamed: J2.S, U2.4, U3.4
unnamed: J2.T, U3.5
unnamed: J3.1, R3.1
unnamed: J5.2, Q1.3
unnamed: J11.1, R4.1
unnamed: R2.1, U2.1
unnamed: R5.1, U3.1
PbTrigIn: J7.1, J9.12, SW2.2
Poll: J9.10, SW3.2
SensorIn: J6.2, J10.3
Shutter: D2.2, J10.7
Spare: J9.7, R4.2

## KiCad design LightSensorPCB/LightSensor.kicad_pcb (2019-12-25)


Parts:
J1: Sensor; TerminalBlock_TE_282834-3_1x03_P2.54mm_Horizontal
Q1: SFH309; LED_D3.0mm_Clear
R1, R2: 10K; R_Axial_DIN0207_L6.3mm_D2.5mm_P7.62mm_Horizontal

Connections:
+3V3: J1.1, Q1.1 (C)
GND: J1.3, R2.1
unnamed: J1.2, R1.1
unnamed: Q1.2 (E), R1.2, R2.2


Board: 2 copper layers, 26.7 x 10.2 mm, 4 parts (0 on the bottom side), 4 nets.

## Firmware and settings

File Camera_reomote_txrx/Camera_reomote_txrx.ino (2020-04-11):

//++++++++++++++++++++++++++++++++++++++++++++++++++++++++++++++d
// rf65/rf95 (lora) RocketTrig
// https://github.com/chrocket/RemoteCameraTrigger
// By Curtis Heisey
// For use with Adafruit 3176 (RFM69( or Adafruit 3178 (LoRo RFM95) Feather M0 Packet radio modules
//  SX1276 LoRa® 
//
// Requires RadioHead libs
// https://www.airspayce.com/mikem/arduino/RadioHead/index.html
// Download from Adafruit https://cdn-learn.adafruit.com/assets/assets/000/035/106/original/RadioHead-1.62.zip?1472068723
// Using (raw) unaddressed broadcast send
// Demonstrates the use of AES encryption, setting the frequency and modem 
// configuration

/* Libs
 *  LowPowerLab/RFM69  (Download from Adfaruit).
 *  CRC32 by Christopher Baker  - install using Arduino IDE library manager
 *  */

 // Pick one module of the other

// #define MODULE_RFM69
// #undef MODULE_RFM95

 #undef MODULE_RFM69
 #define MODULE_RFM95

#include <SPI.h>


  #define RFM69_CS      8
  #define RFM69_INT     3
  #define RFM69_RST     4
 #define LED_PIN           13
  
// Singleton instance of the radio driver
#if defined(MODULE_RFM69)

 
  #include <RH_RF69.h>
  RH_RF69 radio_m0(RFM69_CS, RFM69_INT);  // Adafruit 3176
  #define MAX_MESSAGE_LEN RH_RF69_MAX_MESSAGE_LEN
#else
  #include <RH_RF95.h>
  #define RFM95_CS 8
  #define RFM95_RST 4
  #define RFM95_INT 3
   RH_RF95 radio_m0(RFM95_CS, RFM95_INT);  // Adafruit 3178
   #define MAX_MESSAGE_LEN RH_RF95_MAX_MESSAGE_LEN
#endif




#include <CRC32.h>
// https://github.com/bakercp/CRC32/blob/master/examples/CRC32/CRC32.ino

void printChipId(char *buf) {
  volatile uint32_t val1, val2, val3, val4;
  volatile uint32_t *ptr1 = (volatile uint32_t *)0x0080A00C;
  val1 = *ptr1;
  volatile uint32_t *ptr = (volatile uint32_t *)0x0080A040;
  val2 = *ptr;
  ptr++;
  val3 = *ptr;
  ptr++;
  val4 = *ptr;

  

  sprintf(buf, "%8x%8x%8x%8x", val1, val2, val3, val4);
 
}

/************ Radio Setup ***************/

// ISM 33cm band USA 902-928 MHZ
#define FREQ 915.3
#define RF95_FREQ FREQ
#define RF69_FREQ FREQ



// inputs
const unsigned int LOWHIGH_TRIGGER_IN_PIN = 5; // If armed, Low to high transition will trigger
const unsigned int HIGHLOW_TRIGGER_IN_PIN=17;  // If armed, High to low transition will trigger
const unsigned int PUSH_IN_PIN=14; // Push button trigger override ("arm" does not have to be set)
const unsigned int ARM_IN_PIN=15;  // Push button to arm sensor
const unsigned int POLLREQUEST_IN_PIN=16;  // Push button to send roll call poll request to other nodes
const unsigned int DELAYMS_PIN=18;  // Pot on analog in to set delay 0-200 ms
const unsigned int SPARE_PIN=19;  // Reserved for future use

// outputs
// LED_OUT 13
const unsigned int BUZZER_OUT_PIN= 10;            // Pin to audible indicator
const unsigned int CAMERA_TRIGGER_OUT_PIN = 12;   // Pin for focus opto-isolator
const unsigned int CAMERA_FOCUS_OUT_PIN = 11;     // Pin for shtter opto-isoloatr
const unsigned int AUX_OUT_PIN = 9;               // Pin for 2nd trigger output
const unsigned int ARM_INDICATOR_OUT_PIN = 6;     // Indicates sensor is armed, turns laser on

const unsigned int  ON_TIME_MS = 2000 ;          // Camera bulb on time when trigger fires (typical vals 1-3 seconds)      
const unsigned int  SHORT_TIME_MS = 200;

uint32_t myId_i=0;
char myId[3]={'abc'};
// Dont put this on the stack:
uint8_t buf[MAX_MESSAGE_LEN];
//uint8_t buf[RH_RF95_MAX_MESSAGE_LEN];
char radiopacket[5];

bool isArmed = false;

#if defined(ADAFRUIT_FEATHER_M0) // Feather M0 w/Radio
//TODO need to check for Adafruit Feather M0
#endif






/*
 * NonBlockingTimer CLASS DEFINITION
 */
class NonBlockingTimer {
  protected:
    bool isPressed=LOW;
    unsigned long timeFireOn;
    unsigned long nextChangeTime = 0;
  private:
    NonBlockingTimer(){};
  public:
     NonBlockingTimer(unsigned int timeFireOnIn){
          timeFireOn=timeFireOnIn;     
     }
     void fire(){
      isPressed  = HIGH;
      unsigned long currentTime = millis();
      nextChangeTime = currentTime + timeFireOn;        
     }
    bool check() {
      unsigned long currentTime = millis();
      if(currentTime >= nextChangeTime) {
        isPressed = LOW;
      }
      
      return isPressed;
    }
    bool isBPressed(){
       return isPressed;    
    }
};
/*
 * FireTimer CLASS DEFINITION
 */
class FireTimer: public NonBlockingTimer{
  private:
    byte pinLED;

  public:
    FireTimer(byte pinLED, unsigned long timeLedOn):NonBlockingTimer(timeLedOn) {
      this->pinLED = pinLED;
      pinMode(pinLED, OUTPUT);
      isPressed=LOW;
    }
     void fire(){
      isPressed  = HIGH;
      digitalWrite(pinLED, isPressed);
      unsigned long currentTime = millis();
      nextChangeTime = currentTime + timeFireOn;        
     }

    
    // Checks whether it is time to turn on or off the Output
    bool check() {
      unsigned long currentTime = millis();
      if(currentTime >= nextChangeTime) {
          // Turn output off when time expires
          isPressed = LOW;

      }
       digitalWrite(pinLED, isPressed);
       return isPressed;    
    }

};

// Definition of output triggers
FireTimer cameraTriggerTimer(CAMERA_TRIGGER_OUT_PIN, ON_TIME_MS );
FireTimer cameraTriggerTimerShort(CAMERA_TRIGGER_OUT_PIN, 50 );
FireTimer auxTriggerTimer(AUX_OUT_PIN, SHORT_TIME_MS ); 
FireTimer txReceivedLEDTimer(LED_PIN, SHORT_TIME_MS ); 
// These timers used to debounce buttons
NonBlockingTimer pollNonBlockingPressed( SHORT_TIME_MS ); 
NonBlockingTimer armNonBlockingPressed( SHORT_TIME_MS ); 



void setup() 
{

   // read unique CPU Id
  char bufId[33];
  printChipId(bufId);
  myId_i = CRC32::calculate(bufId, 32); // compute checksum
  Serial.print("My id = ");
  Serial.println(myId_i);
  myId_i = myId_i%1000;
  sprintf(myId,"%3d",myId_i); 
 radiopacket[1]=myId[0];
 radiopacket[2]=myId[1];
 radiopacket[3]=myId[2]; 
 radiopacket[4]='N'; // isArmed

// Arm indicator LED
  pinMode(ARM_INDICATOR_OUT_PIN, OUTPUT);
  digitalWrite(ARM_INDICATOR_OUT_PIN, isArmed);
  pinMode(CAMERA_FOCUS_OUT_PIN, OUTPUT);
  digitalWrite(CAMERA_FOCUS_OUT_PIN, LOW);

// Define input pins
  pinMode(LOWHIGH_TRIGGER_IN_PIN,INPUT);
  pinMode(HIGHLOW_TRIGGER_IN_PIN,INPUT_PULLUP);
  pinMode(POLLREQUEST_IN_PIN, INPUT_PULLUP);
  pinMode(ARM_IN_PIN, INPUT_PULLUP);
  pinMode(PUSH_IN_PIN, INPUT_PULLUP); 
  pinMode(DELAYMS_PIN, INPUT);
  pinMode(SPARE_PIN, INPUT_PULLUP);

  

  Serial.println("CWH Camera Trigger RFM69/RFM95 TXRX!");
  Serial.println();

    // RFM69 Reset pin definition   
#if defined(MODULE_RFM69)
  pinMode(RFM69_RST, OUTPUT);
  digitalWrite(RFM69_RST, LOW);
  
#else
   pinMode(RFM95_RST, OUTPUT);
  digitalWrite(RFM95_RST, HIGH);

#endif   
  

  Serial.begin(115200);
  // Uncomment to not start until serial console is attached (for debugging)
  /*
  while (!Serial) {
    delay(1);
  }
*/
  delay(100);


  // manual reset
  
#if defined(MODULE_RFM69)
  digitalWrite(RFM69_RST, HIGH);
  delay(10);
  digitalWrite(RFM69_RST, LOW);
  delay(10);
  Serial.println("Using module RFM65");
#else
    Serial.println("Using module RFM95");

    
#endif   
  

  while (!radio_m0.init()) {
    Serial.println("LoRa radio init failed");
    Serial.println("Uncomment '#define SERIAL_DEBUG' in RH_RF95.cpp for detailed debug info");
    while (1);
  }
  Serial.println("LoRa radio init OK!");

  // Defaults after init are 434.0MHz, modulation GFSK_Rb250Fd250, +13dbM
  if (!radio_m0.setFrequency(FREQ)) {
    Serial.println("setFrequency failed");
    while (1);
  }
  Serial.print("Set Freq to: "); Serial.println(FREQ);
  


  // If you are using a high power RF69 eg RFM69HW, you *must* set a Tx power with the
  // ishighpowermodule flag set like this:
 #if defined(MODULE_RFM69)
     radio_m0.setTxPower(20, true);  // range from 14-20 for power, 2nd arg must be true for 69HCW 
  #else
      radio_m0.setTxPower(23, false);   
  #endif
  



  // The encryption keyhas to be the same as the one in the server
  uint8_t key[] = { 0x01, 0x02, 0x03, 0x04, 0x05, 0x06, 0x07, 0x08,
                    0x01, 0x02, 0x03, 0x04, 0x05, 0x06, 0x07, 0x08};
#if defined(MODULE_RFM69)
 radio_m0.setEncryptionKey(key);
#else
// no encryption
#endif
 
  

  Serial.print("RFM69/95 radio @");  Serial.print((int)FREQ);  Serial.println(" MHz");
   tone(BUZZER_OUT_PIN, 100 /* hz*/, 2000 /* ms */);




}




void loop() {

     // Update timer values
    cameraTriggerTimer.check();
    auxTriggerTimer.check();
    txReceivedLEDTimer.check();
    pollNonBlockingPressed.check();
    armNonBlockingPressed.check();
    cameraTriggerTimerShort.check();

    // Read delay pot value
    int delayms = analogRead(DELAYMS_PIN);

   // TRIGGER OVERRIDE PB
   // If user presses "fire" push button, it will trigger outputs
   // This overrides any sensor values;  "isArmed" does not have to be set
   if(   !digitalRead(PUSH_IN_PIN)    ){     
      // fire outputs    
      cameraTriggerTimer.fire();
      auxTriggerTimer.fire();
             
     // Trigger destination nodes
     radiopacket[0]= 'T';     
     radio_m0.send((uint8_t *)radiopacket, strlen(radiopacket));
     radio_m0.waitPacketSent();   
     
     Serial.print("PB Trigger Override, Sending Trigger out "); Serial.println(radiopacket);
      // clear isArmed flag state variable
      isArmed = false;
      radiopacket[4]='N';
   }

  // SENSOR TRIGGER INPUT
  // If armed and get a sensor trigger
  // fire things and send a T out
  // set isArmed to false
  if( isArmed && 
    (digitalRead(LOWHIGH_TRIGGER_IN_PIN) || !digitalRead(HIGHLOW_TRIGGER_IN_PIN))
    ){

      
      // fire outputs
      cameraTriggerTimer.fire();
      auxTriggerTimer.fire();

      // clear isArmed flag state variable
      isArmed = false;
      radiopacket[4]='N';
      
    // Trigger destination nodes
     radiopacket[0]= 'T';  
     
     radio_m0.send((uint8_t *)radiopacket, strlen(radiopacket)); 
     radio_m0.waitPacketSent();
     radio_m0.send((uint8_t *)radiopacket, strlen(radiopacket)); // send twice
     radio_m0.waitPacketSent();
     Serial.print("Sensor Trigger - Sending T command ");Serial.println(radiopacket);    
  }

   // POLL REQUEST PB
   // send out a message for Rx to echo their IDs
  if(   !digitalRead(POLLREQUEST_IN_PIN)  &&  
     !pollNonBlockingPressed.isBPressed()  ){

       // Poll requeset to destination nodes
       radiopacket[0]= 'P';      
       radio_m0.send((uint8_t *)radiopacket, strlen(radiopacket));
       radio_m0.waitPacketSent();
       Serial.print("Poll request PB, sending roll call request "); Serial.println(radiopacket);
       cameraTriggerTimerShort.fire(); // fire camera briefly
       pollNonBlockingPressed.fire();
        tone(BUZZER_OUT_PIN, 1000 /* hz*/, 200 /* ms */);
   }
      
  // ARM PB
  // Send arm message out
  // set isArm flag to true
  if(  !digitalRead(ARM_IN_PIN) &&
   !armNonBlockingPressed.isBPressed()  ){
   
      isArmed = true;
      radiopacket[0]= 'A';
      radio_m0.send((uint8_t *)radiopacket, strlen(radiopacket));
      radio_m0.waitPacketSent();
      
     
     Serial.print("Arm PB,  Sending Arm command ");Serial.println(radiopacket);
     tone(BUZZER_OUT_PIN, 100 /* hz*/, 100 /* ms */);
     armNonBlockingPressed.fire();

  }
  digitalWrite(ARM_INDICATOR_OUT_PIN, isArmed);
  digitalWrite(CAMERA_FOCUS_OUT_PIN, isArmed);

 // Receive commands    
 if (radio_m0.available())
  {
    uint8_t len = sizeof(buf);
    if (radio_m0.recv(buf, &len)) {
      if (!len) return;
     // buf[len] = 0;
      buf[5] = 0;
      /*
      Serial.print("Received [");
      Serial.print(len);
      Serial.print("]: ");
      Serial.println((char*)buf);
      Serial.print("RSSI: ");
      Serial.println(radio_m0.lastRssi(), DEC);
*/

    txReceivedLEDTimer.fire(); // blink the LED indicating a tx received

    // arm command
    if (strstr((char *)buf, "A")) {
           isArmed = true;     
           Serial.println("Received Arm commmand");
           radiopacket[4]='Y';
           tone(BUZZER_OUT_PIN, 100 /* hz*/, 100 /* ms */);
      }
    // trigger command
    if (strstr((char *)buf, "T")) {            
            // fire outputs     
            cameraTriggerTimer.fire();
            auxTriggerTimer.fire(); 
            Serial.println("Received Trigger commmand");  
            tone(BUZZER_OUT_PIN, 450 /* hz**/, SHORT_TIME_MS /* ms */); 
            // clear isArmed flag state variable
            isArmed = false;
            radiopacket[4]='N';                     
      }
      // poll request
      if (strstr((char *)buf, "P")) {   
            Serial.println("Received request for poll, sending id back"); 
            radiopacket[0]= 'R'; 

 
            delay(  myId_i );
            radio_m0.send((uint8_t *)radiopacket, strlen(radiopacket));
            radio_m0.waitPacketSent();  

                  
           cameraTriggerTimerShort.fire();
      }
      // poll response back from poll request
      if (strstr((char *)buf, "R")) { 
        Serial.print("Got an id response back: ");
        Serial.print((char*)buf);
        Serial.print(", RSSI: ");
        Serial.println(radio_m0.lastRssi(), DEC);
        tone(BUZZER_OUT_PIN, 1500 /* hz*/, 100 /* ms */);
      }

    } 
  }// end Rx loop
}// end loop

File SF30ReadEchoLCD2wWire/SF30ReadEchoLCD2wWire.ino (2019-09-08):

#include <RFM69.h>
#include <RFM69registers.h>
#include <RFM69_ATC.h>
#include <RFM69_OTA.h>

/*
  SF30 Serial Demo V1.0 
  Author: Zakia Ben Youss
  Copyright (c) 2015 Parallax Inc.t

This demo uses the serial input on the SF30 High Speed Laser Rangefinder to initiate a new range value to be sent serially to the Arduino. 
Detects distance and displays it in meters on the Arduino Terminal.

NOTE:
-This demo assumes that the SF30 is set to a UART speed of 38400 Baud.
-This demo assumes that the SF30 is set to a 0.03m Snapshot Resolution. 
-This demo assumes that the SF30 is set to a 1144/sec Serial Port Update Rate.

See the product manual and instructions for details on changing the settings

You can find the manual by going to www.parallax.com and searching for SF30, and clicking Downloads & Documentation on the product page.

Wiring Diagram:

Pin_GND (Black)  On SF30 Laser Rangefinder - GND (Vss On Some Boards)
Pin_+5V (Red)    On SF30 Laser Rangefinder - +5V (Vdd On Some Boards)
Pin_TXD (Yellow) On SF30 Laser Rangefinder - Arduino RX Pin (0)
Pin_RXD (Orange) On SF30 Laser Rangefinder - Arduino TX Pin (1)

  
  http://learn.parallax.com/propeller-c-simple-devices/
  
*/
                                        
#include <Wire.h>
#include "Kalman.h"

#define DISPLAY_ADDRESS_LCD 0x72 //This is the default address of the OpenLCD

#define terminal_baud_rate    115200                                   // terminal baud rate 115200

#define sf30_baud_rate        115200      // Sf30 baud rate  (Can be changed, refer to the sf30 manual)

// The pins used for the second serial port 0, 1  (Serial1)

unsigned long time_now_ms;
unsigned long time_last_ms;
unsigned long trigger_time_ms;
bool isTriggered;
float valuePot=0;
unsigned long last_report_time;
// q process noise cov, r measurement noise cov, p est error cov, initial value 
//Kalman myFilter(0.125, 32, 50, 0);
Kalman myFilter(10, 5, 20, 25);

const unsigned int  ON_TIME_MS = 1000 ;          // Camera bulb on time when trigger fires (typical vals 1-3 seconds)      
const unsigned int  CAMERA_PIN = 8  ;            // Pin for camera opto-isolator
const unsigned int LED_PIN1 = 4  ;              // pin for LED that indicates trigger
const unsigned int LED_PIN2 = 9  ;              // pin for LED that indicates trigger
const unsigned int TRIGGER_PIN2 = 5;
const int POT_IN_ANALOG_PIN = A5;  // Analog input pin that the potentiometer is attached to
const float MAX_RANGE_FT = 160.0  ;        // Max range of SF-30B is 50 m
//const float CM_TO_INCH = 0.0328084;
const float CM_TO_INCH = 0.0393701;
const float LCD_UPDATE_MS = 300;






// sparkfun
#define ser SerialUSB
// Adafruit
// #define ser Serial
#define SF30_SERIAL Serial1
void setup()                                          
{
  ser.begin(terminal_baud_rate);                                     // Open the main USB serial port on the Arduino ready for the terminal application
                                                      // Wait for serial port to connect.
  SF30_SERIAL.begin(sf30_baud_rate);                                    // Open the second serial port to connect to the sf30

  Wire.begin(); //Join the bus as master

  //By default .begin() will set I2C SCL to Standard Speed mode of 100kHz
  //Wire.setClock(400000); //Optional - set I2C SCL to High Speed Mode of 400kHz

  pinMode(CAMERA_PIN, OUTPUT);
  digitalWrite(CAMERA_PIN, LOW);
 
  pinMode(LED_PIN2, OUTPUT);
  digitalWrite(LED_PIN2, LOW);

  pinMode(LED_PIN1, OUTPUT);
  digitalWrite(LED_PIN1, LOW);
  
  pinMode(TRIGGER_PIN2, OUTPUT);
  digitalWrite(TRIGGER_PIN2, LOW);



  //Send the reset command to the display - this forces the cursor to return to the beginning of the display
  Wire.beginTransmission(DISPLAY_ADDRESS_LCD);
  Wire.write('|'); //Put LCD into setting mode
  Wire.write('-'); //Send clear display command
  Wire.endTransmission();

  //defaults
  time_last_ms=0;
  trigger_time_ms=0;
  isTriggered=false;
  last_report_time =micros();
}

  


//Given a number, i2cSendValue chops up an integer into four values and sends them out over I2C
void i2cSendValue(float value, int threshold_ft, bool trigger)
{
  Wire.beginTransmission(DISPLAY_ADDRESS_LCD); // transmit to device #1

  Wire.write('|'); //Put LCD into setting mode
  Wire.write('-'); //Send clear display command

//  char floatrep[5];
//  snprintf(floatrep, sizeof(floatrep), "%.1f ", &value);

  Wire.print("D:");
  Wire.println(value);
  Wire.print("T: ");
  Wire.print(threshold_ft);
  Wire.print(" Tr: ");
  Wire.print(trigger);

  Wire.endTransmission(); //Stop I2C transmission
}

float takeReading()
{
  // Flush buffer
  while (SF30_SERIAL.available())
    SF30_SERIAL.read();
  
  while (SF30_SERIAL.available() == 0);

  while (SF30_SERIAL.available() == 1);

  while (SF30_SERIAL.available() == 2);


  byte byte0 = SF30_SERIAL.read();
  byte byte1 = SF30_SERIAL.read();
  byte byte2 = SF30_SERIAL.read();
  /*
  ser.println(byte0);
  ser.println(byte1); 
   ser.println(byte2);
*/
  float distance = 0.0;

  if (byte1&0x80)
    distance = (( byte1&0x7F)*128)+(byte0&0x7F);
  else
    distance = (( byte2&0x7F)*128)+(byte1&0x7F);

  return distance*CM_TO_INCH;
}

bool takeReading(float &distance, unsigned long &time_of_reading)
{
  // Flush buffer
  while (SF30_SERIAL.available())
    SF30_SERIAL.read();
  
  while (SF30_SERIAL.available() == 0);

  while (SF30_SERIAL.available() == 1);

  while (SF30_SERIAL.available() == 2);

  time_of_reading
  = micros(); // time of reading

  
  byte byte0 = SF30_SERIAL.read();
  byte byte1 = SF30_SERIAL.read();
  byte byte2 = SF30_SERIAL.read();
  /*
  ser.println(byte0);
  ser.println(byte1); 
   ser.println(byte2);
*/

  float reading;

  if (byte1&0x80){
    reading = (( byte1&0x7F)*128)+(byte0&0x7F);
  }else if( byte2&0x80) {
    reading = (( byte2&0x7F)*128)+(byte1&0x7F);
  } else{
    return false;  // bad reading
  }

   distance = reading *CM_TO_INCH;
   if( distance > MAX_RANGE_FT){
     distance = MAX_RANGE_FT;
   }
   
  return true; // good reading
}



bool checkTrigger(float distance, float threshold_ft){

   bool alarm = distance < threshold_ft;

   if( alarm && ! isTriggered){
      isTriggered = true;
      trigger_time_ms = millis();
      digitalWrite(CAMERA_PIN, HIGH);
      digitalWrite(LED_PIN1, HIGH);
      digitalWrite(LED_PIN2, HIGH);
      digitalWrite(TRIGGER_PIN2, HIGH);
      ser.println("Setting trigger");
   }
   if( isTriggered){
      unsigned long now = millis();
      if( now - trigger_time_ms > ON_TIME_MS){
          isTriggered = false;
          digitalWrite(CAMERA_PIN, LOW);
          digitalWrite(LED_PIN1, LOW);
          digitalWrite(LED_PIN2, LOW);
          digitalWrite(TRIGGER_PIN2, LOW);
          ser.println("Clearing trigger");
      }
   }

   return isTriggered;
}
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

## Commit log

2019-08-20 Basic working SF-30B Lidar with LCD and camera trigger
2019-09-08 Attached the RF link
    Attached the RF link to Adafruit M0 Feather on output pin 5
2019-09-08 Voltage divider read
2019-09-08 Camera_remote_tx/rx
    RF lin camera trigger
    RadioHead69_AddrDemo_TX_redboard.ino tried to hook RFM69 directly to redboard, but didn't work
    [Camera_remote_rx.ino, Camera_reomote_tx.ino, RadioHead69_AddrDemo_RX.ino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]
2019-12-15 Add files via upload
    Added timer so can only press button every 0.1 sec
2019-12-17 Add files via upload
    Adding Adafruit M0 Packet Radio Board docs
2019-12-23 Add files via upload
    Program to get unique board id for Feather M0
2019-12-25 Add files via upload
    PCB stuff
    [CameraTrigger-B_Cu.gbr, CameraTrigger-B_Mask.gbr, CameraTrigger-B_Paste.gbr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]
2019-12-25 Add files via upload
    Updated pinout to PCB
2019-12-25 Add files via upload
    Updated pinout
    [Heisey pinout.xlsx]
2020-01-04 Add files via upload
    Updated BOM to fix a few hole placements
    [CameraTrigger.xlsx]
2020-01-04 Add files via upload
    Added Adafruit 3176 Packet radio to BOM
    Added 2.5 mm 3-position camera jack as alternative to J2
    [CameraTrigger.xlsx]
2020-01-04 Add files via upload
    Switching pins 10,11
2020-01-06 Add files via upload
    Rev2 board
    [CameraTrigger R2.kicad_pcb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]
2020-01-19 Add files via upload
    Fixes on R2 board
    [CameraTrigger.kicad_pcb, CameraTrigger.sch, CameraTriggerR2MouserBOM.xlsx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]
2020-01-23 Rev2B changes
    [CameraTrigger.kicad_pcb, CameraTrigger.sch, CameraTriggerR2MouserBOM.xlsx]
2020-01-29 Moved jacks closer to board edge
    [CameraTrigger-B_Cu.gbr, CameraTrigger-B_Mask.gbr, CameraTrigger-B_Paste.gbr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]
2020-02-27 Add files via upload
    Made poll click the camera, briefly.
    Send trigger message out twice after a sensor goes off
2020-03-07 Add files via upload
    Final build before switching over to LoRa
2020-03-12 Add files via upload
    Updated BOM with mounting hardware
    [CameraTriggerR2MouserBOM.xlsx]
2020-03-15 Unit test codes for zio ultrasound detector, distance sensor, and oled display
2020-03-19 Delete Camera_reomote_txrx.ino
    Oops file in wrong place
    [Camera_reomote_txrx.ino]
2020-04-11 Add files via upload
    Fixing bug so that trigger override fires camera right away
    [Camera_reomote_txrx.ino]
2020-04-17 Add files via upload
    Sensor node only
    [CameraTriggerSensorNodeOnly-B_Cu.gbr, CameraTriggerSensorNodeOnly-B_Mask.gbr, CameraTriggerSensorNodeOnly-B_Paste.gbr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]
2020-04-20 Add files via upload
    Adding LightSensor2
    [CameraTriggerR2MouserBOM.xlsx, CameraTriggerSensorNodeOnly.kicad_pcb, CameraTriggerSensorNodeOnlyXLS.xlsx]
2020-04-20 Add files via upload
    LightSensor2 (Alex) and BreakWire schematic
    [CameraTriggerBreakWire.kicad_pcb, CameraTriggerBreakWire.sch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]
2020-04-26 Add files via upload
    Rdo SCK SDL to correct pins
    [CameraTriggerSensorNodeOnly.kicad_pcb, CameraTriggerSensorNodeOnly.sch]
2020-04-28 Add files via upload
    Adding Arm switch back in
    Adding transistor driver on buzzer
    [CameraTriggerSensorNodeOnly.kicad_pcb, CameraTriggerSensorNodeOnly.sch]
2020-05-13 Add files via upload
    Broke schematic into hierarchical sheets
    [AdafruitBT.sch, Buzzer.sch, CameraIO.sch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]
2020-05-29 Add files via upload
    Adding XLR connector
    [Buzzer.sch, CameraIO.sch, CameraTrigger.sch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]
2020-05-29 Add files via upload
    Added XLR connector
    [CameraTriggerSensorNodeOnly-B_Cu.gbr, CameraTriggerSensorNodeOnly-B_Mask.gbr, CameraTriggerSensorNodeOnly-B_Paste.gbr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]
2020-05-31 Add files via upload
    Production version
    [CameraTriggerSensorNodeOnly-B_Cu.gbr, CameraTriggerSensorNodeOnly-B_Mask.gbr, CameraTriggerSensorNodeOnly-B_Paste.gbr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]
2020-06-02 Add files via upload
    Added comment to schematic for XLR connector (male).
    [CameraTriggerSensorNodeOnly.sch]
2020-12-24 Add files via upload
    JCBPCB Assembly
    [BLE.sch, Buzzer.sch, CameraIO.sch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]
2020-12-24 Add files via upload
    Rotated D7
    [CameraTriggerR3SMD-top-pos updated.xlsx]
2020-12-25 Add files via upload
    Sensor node only is working
